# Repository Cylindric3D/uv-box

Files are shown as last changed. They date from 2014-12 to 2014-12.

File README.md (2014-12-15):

Note that documentation and schematics are also available as images in the [GitHub Pages](https://cylindric3d.github.io/uv-box/) site for this project.

Controller Schematic
Controller Board

Important Plots
===============
* Controller Schematic
* Controller Board: B.Cu
* Controller Board: F.SilkS
* LED Panels Schematic
* LED Panels Board: B.Cu

Tips for Creating the PCB
=========================
For creating the PCBs with UV-sensitive boards:

1. Text on the B.Cu layer should appear mirrored
2. Plot only the bottom copper "B.Cu" layer to PDF, do not mirror it - it should look mirrored in the PDF.
   This is because you want the ink to be as close to the photo-sensitive surface of the PCB as possible.
3. Print the B_Cu.pdf onto transparencies suitable for your printer.

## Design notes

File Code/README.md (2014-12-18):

Basic States
------------

* **STATE_STARTUP**
The firmware starts in the Startup state while setting up. In this state no user input is accepted. After startup is complete, the state moves to *STATE_READY*.

* **STATE_READY**
The firmare initially transitions to Ready once it has started up. In this state the user can use the encoder to select a time, and use the button to start the countdown. The LEDs are off. Clicking the button changes the state to *STATE_ACTIVE*.

* **STATE_ACTIVE**
This is the state when the countdown is running, and the LEDs are on. The user can use the button to stop the countdown. Note that the user can still use the encoder to bump the time up or down. After the countdown is complete, the state changes to *STATE_RESETTING*.

* **STATE_RESETTING**
This is a simple reset-state. After a preset time, the display will reset and the state will return to *STATE_READY*.

State Transitions
-----------------
* *STATE_STARTUP*
  * automatically to *STATE_READY*
* *STATE_READY*
  * button-click causes change to *STATE_ACTIVE*
* *STATE_ACTIVE* 
  * button-click causes change to *STATE_RESETTING*
  * countdown complete causes change to *STATE_RESETTING*
* *STATE_RESETTING*
  * automatically to *STATE_READY*

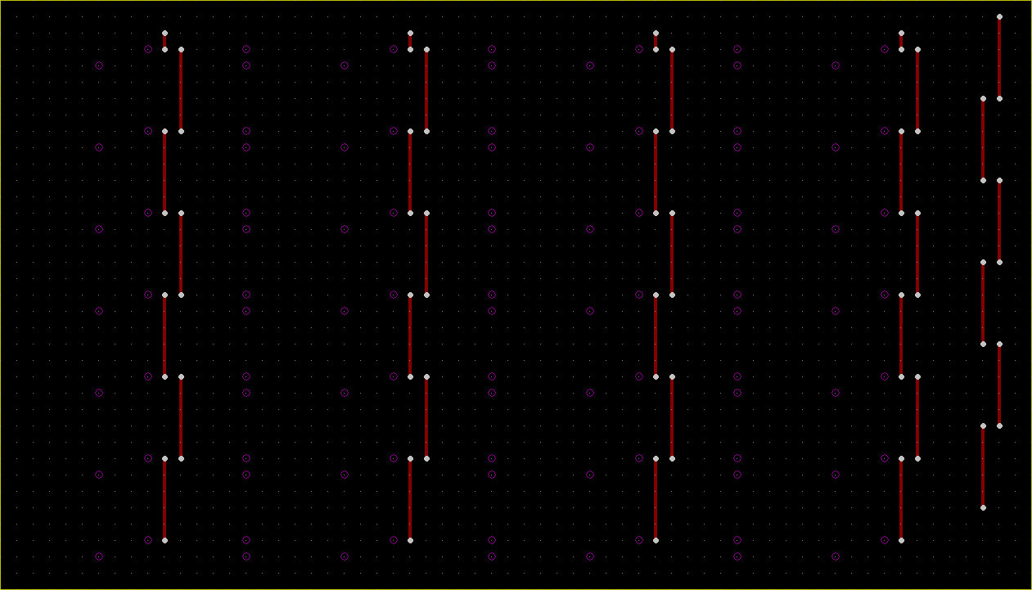
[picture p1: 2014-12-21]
Plans/led_panel-veroboard-bottom.png

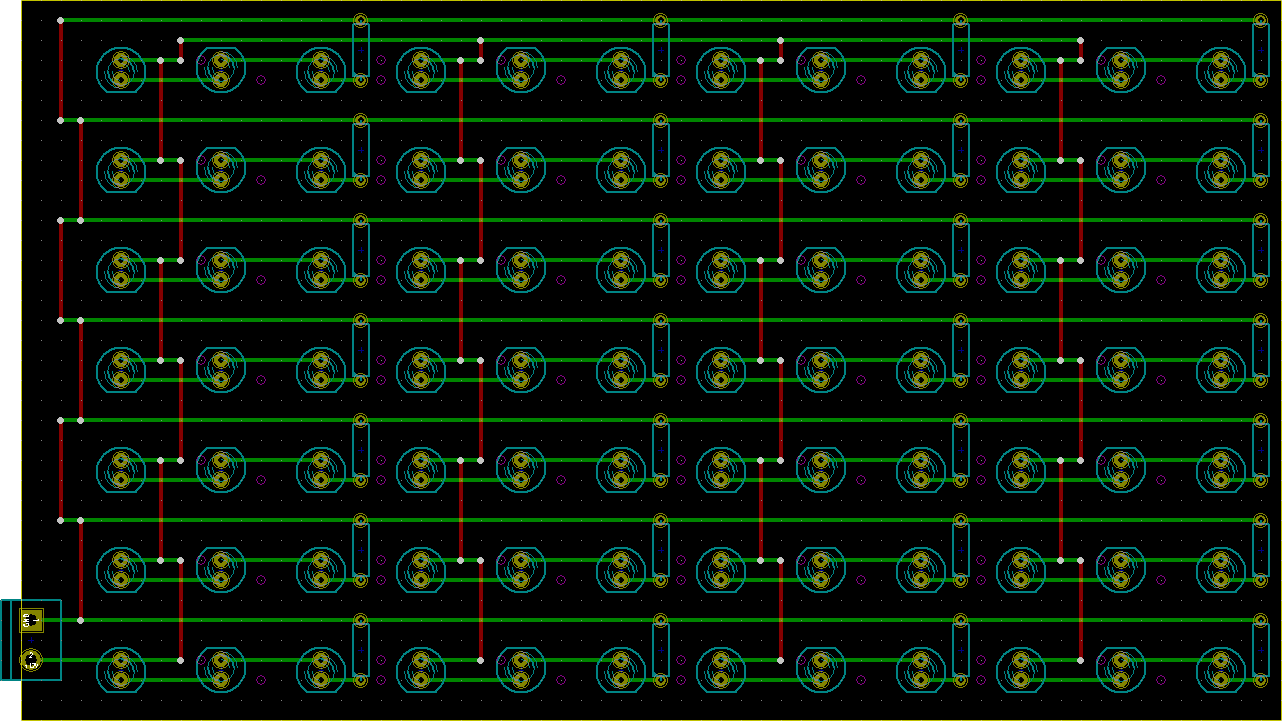
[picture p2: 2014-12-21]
Plans/led_panel-veroboard-top.png

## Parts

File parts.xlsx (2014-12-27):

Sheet: Sheet1
Build
Seller | Part | Item | Ref | Qty | £ Per | £ | PP | Subtotal
 | Controller | Capacitor, ceramic disk: 0.1µF | C4, C1, C2 | 3 |  | £0.00 |  | £0.00
 | Controller | Capacitor, ceramic disk: 0.33µF | C3 | 1 |  | £0.00 |  | £0.00
 | Controller | Resistor: 100kΩ | R4 | 1 |  | £0.00 |  | £0.00
 | Controller | Resistor: 10kΩ | R2 | 1 |  | £0.00 |  | £0.00
 | Controller | Resistor: 120Ω | R12 | 1 |  | £0.00 |  | £0.00
 | Controller | Resistor: 33Ω | R1, R5-11 | 8 |  | £0.00 |  | £0.00
 | Controller | Serial-in, parallel-out shift-register: 74HC595 | U2 | 1 |  | £0.00 |  | £0.00
 | Controller | Rotary Encoder: Alps EC12E2420404 | ENC1 | 1 | £0.77 | £0.77 |  | £0.77
 | Controller | Arduino Pro Micro | U3 | 1 |  | £0.00 |  | £0.00
 | Controller | 4-Digit, 7-segment display: ATA3492BW | LED_DISPLAY1 | 1 | £1.23 | £1.23 |  | £1.23
 | Controller | Voltage regulator, 5V: LM7805 | U1 | 1 |  | £0.00 |  | £0.00
 | Controller | Push-button switch: MULTICOMP TS0B23 | SW1 | 1 | £0.39 | £0.39 |  | £0.39
 | Controller | MOSFET: P55NF | Q1 | 1 |  | £0.00 |  | £0.00
 | Controller | Pin Header Angled | P1, P2, P3 | 6 |  | £0.00 |  | £0.00
 | Controller | DIP Socket | U2 | 16 |  | £0.00 |  | £0.00
 | Controller | SIP Socket | LED_DISPLAY1, U3 | 40 |  | £0.00 |  | £0.00
 | Panel |  |  |  |  | £0.00 |  | £0.00
Seller | Part | Item | Qty | £ Per | £ | PP | Subtotal
eBay | Panel | 50 x Ultra Violet / UV / Purple LED 5mm - 3000mcd - UK Forward Voltage : 3.2v - 3.8v, Forward Current : 20mA | 4 | £3.69 | £14.76 | £0.99 | £15.75
eBay | Panel | 100 x 1/4W 5% Carbon film Resistors - 330Ω | 1 | £0.99 | £0.99 | £0.99 | £1.98 |  | Checked
eBay | Controller | 12V UK DC Power Plug 2A and Power Socket | 1 | £6.99 | £6.99 | £0.00 | £6.99
eBay | Panel | Stripboard PCB Prototyping Vero | 2 | £1.89 | £3.78 | £0.88 | £4.66
CPC | Controller | CLIFF ELECTRONIC COMPONENTS - FC681473 - CONNECTOR, RECEPTACLE, DC POWER, 2.1MM | 1 | £0.38 | £0.38 |  | £0.38
eBay | Box | Strut Hinges For Flight Case Lids - One Pair - Nickel Finish | 1 | £4.49 | £4.49 |  | £4.49
eBay | Box | Clear acrylic 4mmx100mmx200mm | 2 | £3.16 | £6.32 |  | £6.32
eBay | Controller | 1 x Silver Aluminium 6mm Shaft Volume Control Potentiometer Knob Hi-Fi Audio | 1 | £1.99 | £1.99 |  | £1.99
CPC |  | 10-pack HARWIN - M20-9820406 - 0.1" VERTICAL SOCKET 4 WAY | 1 | 4.79 | 4.79 |  | 4.79
CPC | Controller | MULTICOMP - 2226A-08 - CRIMP HOUSING, 1 ROW, 8 WAY | 2 | £0.02 | £0.04 |  | £0.04
CPC | Controller | MULTICOMP - 2226TG - CRIMP TERMINAL, 24-28AWG | 100 | £0.01 | £1.00 |  | £1.00
eBay |  | 10x Ceramic Disc Capacitors 50V 47 values | 1 | £0.99 | £0.99 |  | £0.99
Wickes | Box | WICKES GENERAL PURPOSE MDF BOARD 6X1220X2440MM | 1 | £10.99 | £10.99 |  | £10.99
eBay | Box | Acrylic | 2 | £3.16 | £6.32 |  | £6.32
eBay | Box | M4 Bolts - shorter | 12 |  | £0.00 |  | £0.00
eBay | Box | M4 Bolts - longer | 4 |  | £0.00 |  | £0.00
eBay | Box | M4 Nuts | 16 |  | £0.00 |  | £0.00
 |  | Total |  |  |  |  | £66.69
Consumables
Seller | Part | Item | Qty | £ Per | £ | PP | Subtotal
eBay |  | 50 Sheets Inkjet / Laser Overhead Projector Film OHP A4 LabelHeaven Colour | 1 | £8.95 | £8.95 |  | £8.95
CPC |  | KELAN - 141300 - PCB, PHOTO RESIST, S/S, 100X160MM | 2 | £3.70 | £7.40 |  | £7.40
CPC |  | KELAN - 141301 - PCB, PHOTO RESIST, D/S, 100X160MM | 2 | £3.89 | £7.78 |  | £7.78
CPC |  | KEMO ELECTRONIC - E250 - DEVELOPER, 250G | 1 | £4.04 | £4.04 |  | £4.04
CPC |  | CCL/FCEF/25B - FERRIC CHLORIDE SOLUTION | 1 | £5.62 | £5.62 |  | £5.62
 |  | Total |  |  |  |  | £33.79

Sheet: BOM
REF | Type | Footprint | Value
P1 | Pin Header | 1x12 | PROMICRO_A
P2 | Pin Header | 1x12 | PROMICRO_B
P3 | Connector | Bornier2 | PANEL_2
P4 | Connector | Bornier2 | PANEL_1
P5 | Connector | Bornier3 | DIAL
P6 | Connector | Bornier2 | POWER
Q1 | MOSFET | ? | ?
R1 | Resistor | R3 | 10k
R2 | Resistor | R3 | 10k
R3 | Resistor | R3 | 10k
R4 | Resistor | R3 | 1k
R5 | Resistor | R3 | 330R
U1 | Power | TO-220 | LM317T

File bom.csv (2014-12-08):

source | ref | value | footprint
controller | P3 | PANEL_2 | Connect:bornier2
controller | P2 | PANEL_1 | Connect:bornier2
controller | R9 | 10k | Discret:R3
controller | P4 | DIAL | Connect:bornier3
controller | P1 | POWER | Connect:bornier2
controller | U1 | LM317T | Power_Integrations:TO-220
controller | R10 | 330 | Discret:R3
controller | R11 | 1k | Discret:R3
controller | C2 | 0.1uF | Capacitors_ThroughHole:Capacitor4x3RM2.5
controller | C1 | 0.1uF | Capacitors_ThroughHole:Capacitor4x3RM2.5
controller | P5 | SWITCH | Connect:bornier2
controller | U2 | 74HC595 | Sockets_DIP:DIP-16__300
controller | R2 | 33R | Discret:R3
controller | R6 | 33R | Discret:R3
controller | P6 | LED_DISPLAY | Pin_Headers:Pin_Header_Straight_2x08
controller | R4 | 33R | Discret:R3
controller | R3 | 33R | Discret:R3
controller | R7 | 33R | Discret:R3
controller | R8 | 33R | Discret:R3
controller | R5 | 33R | Discret:R3
controller | R1 | 33R | Discret:R3
controller | U3 | Arduino_Pro_Micro | Cylindric:ArduinoProMicro
controller | Q1 | BUZ11 | Transistors_TO-220:TO-220_FET-GDS_Vertical
led_panels | D19 | LED | LEDs:LED-5MM
led_panels | D20 | LED | LEDs:LED-5MM
led_panels | R7 | 120 | Discret:R3
led_panels | P1 | CONN_2 | Connect:bornier2
led_panels | D21 | LED | LEDs:LED-5MM
led_panels | D13 | LED | LEDs:LED-5MM
led_panels | D14 | LED | LEDs:LED-5MM
led_panels | R5 | 120 | Discret:R3
led_panels | D15 | LED | LEDs:LED-5MM
led_panels | D7 | LED | LEDs:LED-5MM
led_panels | D8 | LED | LEDs:LED-5MM
led_panels | R3 | 120 | Discret:R3
led_panels | D9 | LED | LEDs:LED-5MM
led_panels | D1 | LED | LEDs:LED-5MM
led_panels | D2 | LED | LEDs:LED-5MM
led_panels | R1 | 120 | Discret:R3
led_panels | D3 | LED | LEDs:LED-5MM
led_panels | D37 | LED | LEDs:LED-5MM
led_panels | D38 | LED | LEDs:LED-5MM
led_panels | R13 | 120 | Discret:R3
led_panels | D39 | LED | LEDs:LED-5MM
led_panels | D31 | LED | LEDs:LED-5MM
led_panels | D32 | LED | LEDs:LED-5MM
led_panels | R11 | 120 | Discret:R3
led_panels | D33 | LED | LEDs:LED-5MM
led_panels | D25 | LED | LEDs:LED-5MM
led_panels | D26 | LED | LEDs:LED-5MM
led_panels | R9 | 120 | Discret:R3
led_panels | D27 | LED | LEDs:LED-5MM
led_panels | D61 | LED | LEDs:LED-5MM
led_panels | D62 | LED | LEDs:LED-5MM
led_panels | R21 | 120 | Discret:R3
led_panels | D63 | LED | LEDs:LED-5MM
led_panels | D55 | LED | LEDs:LED-5MM
led_panels | D56 | LED | LEDs:LED-5MM
led_panels | R19 | 120 | Discret:R3
led_panels | D57 | LED | LEDs:LED-5MM
led_panels | D49 | LED | LEDs:LED-5MM
led_panels | D50 | LED | LEDs:LED-5MM
led_panels | R17 | 120 | Discret:R3
led_panels | D51 | LED | LEDs:LED-5MM
led_panels | D43 | LED | LEDs:LED-5MM
led_panels | D44 | LED | LEDs:LED-5MM
led_panels | R15 | 120 | Discret:R3
led_panels | D45 | LED | LEDs:LED-5MM
led_panels | D79 | LED | LEDs:LED-5MM
led_panels | D80 | LED | LEDs:LED-5MM
led_panels | R27 | 120 | Discret:R3
led_panels | D81 | LED | LEDs:LED-5MM
led_panels | D73 | LED | LEDs:LED-5MM
led_panels | D74 | LED | LEDs:LED-5MM
led_panels | R25 | 120 | Discret:R3
led_panels | D75 | LED | LEDs:LED-5MM
led_panels | D67 | LED | LEDs:LED-5MM
led_panels | D68 | LED | LEDs:LED-5MM
led_panels | R23 | 120 | Discret:R3
led_panels | D69 | LED | LEDs:LED-5MM
led_panels | D103 | LED | LEDs:LED-5MM
led_panels | D104 | LED | LEDs:LED-5MM
led_panels | R35 | 120 | Discret:R3
led_panels | D105 | LED | LEDs:LED-5MM
led_panels | D97 | LED | LEDs:LED-5MM
led_panels | D98 | LED | LEDs:LED-5MM
led_panels | R33 | 120 | Discret:R3
led_panels | D99 | LED | LEDs:LED-5MM
led_panels | D91 | LED | LEDs:LED-5MM
led_panels | D92 | LED | LEDs:LED-5MM
led_panels | R31 | 120 | Discret:R3
led_panels | D93 | LED | LEDs:LED-5MM
led_panels | D85 | LED | LEDs:LED-5MM
led_panels | D86 | LED | LEDs:LED-5MM
led_panels | R29 | 120 | Discret:R3
led_panels | D87 | LED | LEDs:LED-5MM
led_panels | D121 | LED | LEDs:LED-5MM
led_panels | D122 | LED | LEDs:LED-5MM
led_panels | R41 | 120 | Discret:R3
led_panels | D123 | LED | LEDs:LED-5MM
led_panels | D115 | LED | LEDs:LED-5MM
led_panels | D116 | LED | LEDs:LED-5MM
led_panels | R39 | 120 | Discret:R3
led_panels | D117 | LED | LEDs:LED-5MM
led_panels | D109 | LED | LEDs:LED-5MM
led_panels | D110 | LED | LEDs:LED-5MM
led_panels | R37 | 120 | Discret:R3
led_panels | D111 | LED | LEDs:LED-5MM
led_panels | D145 | LED | LEDs:LED-5MM
led_panels | D146 | LED | LEDs:LED-5MM
led_panels | R49 | 120 | Discret:R3
led_panels | D147 | LED | LEDs:LED-5MM
led_panels | D139 | LED | LEDs:LED-5MM
led_panels | D140 | LED | LEDs:LED-5MM
led_panels | R47 | 120 | Discret:R3
led_panels | D141 | LED | LEDs:LED-5MM
led_panels | D133 | LED | LEDs:LED-5MM
led_panels | D134 | LED | LEDs:LED-5MM
led_panels | R45 | 120 | Discret:R3
led_panels | D135 | LED | LEDs:LED-5MM
led_panels | D127 | LED | LEDs:LED-5MM
led_panels | D128 | LED | LEDs:LED-5MM
led_panels | R43 | 120 | Discret:R3
led_panels | D129 | LED | LEDs:LED-5MM
led_panels | D163 | LED | LEDs:LED-5MM
led_panels | D164 | LED | LEDs:LED-5MM
led_panels | R55 | 120 | Discret:R3
led_panels | D165 | LED | LEDs:LED-5MM
led_panels | D157 | LED | LEDs:LED-5MM
led_panels | D158 | LED | LEDs:LED-5MM
led_panels | R53 | 120 | Discret:R3
led_panels | D159 | LED | LEDs:LED-5MM
led_panels | D151 | LED | LEDs:LED-5MM
led_panels | D152 | LED | LEDs:LED-5MM
led_panels | R51 | 120 | Discret:R3
led_panels | D153 | LED | LEDs:LED-5MM
led_panels | D22 | LED | LEDs:LED-5MM
led_panels | D23 | LED | LEDs:LED-5MM
led_panels | R8 | 120 | Discret:R3
led_panels | P2 | CONN_2 | Connect:bornier2
led_panels | D24 | LED | LEDs:LED-5MM
led_panels | D16 | LED | LEDs:LED-5MM
led_panels | D17 | LED | LEDs:LED-5MM
led_panels | R6 | 120 | Discret:R3
led_panels | D18 | LED | LEDs:LED-5MM
led_panels | D10 | LED | LEDs:LED-5MM
led_panels | D11 | LED | LEDs:LED-5MM
led_panels | R4 | 120 | Discret:R3
led_panels | D12 | LED | LEDs:LED-5MM
led_panels | D4 | LED | LEDs:LED-5MM
led_panels | D5 | LED | LEDs:LED-5MM
led_panels | R2 | 120 | Discret:R3
led_panels | D6 | LED | LEDs:LED-5MM
led_panels | D40 | LED | LEDs:LED-5MM
led_panels | D41 | LED | LEDs:LED-5MM
led_panels | R14 | 120 | Discret:R3
led_panels | D42 | LED | LEDs:LED-5MM
led_panels | D34 | LED | LEDs:LED-5MM
led_panels | D35 | LED | LEDs:LED-5MM
led_panels | R12 | 120 | Discret:R3
led_panels | D36 | LED | LEDs:LED-5MM
led_panels | D28 | LED | LEDs:LED-5MM
led_panels | D29 | LED | LEDs:LED-5MM
led_panels | R10 | 120 | Discret:R3
led_panels | D30 | LED | LEDs:LED-5MM
led_panels | D64 | LED | LEDs:LED-5MM
led_panels | D65 | LED | LEDs:LED-5MM
led_panels | R22 | 120 | Discret:R3
led_panels | D66 | LED | LEDs:LED-5MM
led_panels | D58 | LED | LEDs:LED-5MM
led_panels | D59 | LED | LEDs:LED-5MM
led_panels | R20 | 120 | Discret:R3
led_panels | D60 | LED | LEDs:LED-5MM
led_panels | D52 | LED | LEDs:LED-5MM
led_panels | D53 | LED | LEDs:LED-5MM
led_panels | R18 | 120 | Discret:R3
led_panels | D54 | LED | LEDs:LED-5MM
led_panels | D46 | LED | LEDs:LED-5MM
led_panels | D47 | LED | LEDs:LED-5MM
led_panels | R16 | 120 | Discret:R3
led_panels | D48 | LED | LEDs:LED-5MM
led_panels | D82 | LED | LEDs:LED-5MM
led_panels | D83 | LED | LEDs:LED-5MM
led_panels | R28 | 120 | Discret:R3
led_panels | D84 | LED | LEDs:LED-5MM
led_panels | D76 | LED | LEDs:LED-5MM
led_panels | D77 | LED | LEDs:LED-5MM
led_panels | R26 | 120 | Discret:R3
led_panels | D78 | LED | LEDs:LED-5MM
led_panels | D70 | LED | LEDs:LED-5MM
led_panels | D71 | LED | LEDs:LED-5MM
led_panels | R24 | 120 | Discret:R3
led_panels | D72 | LED | LEDs:LED-5MM
led_panels | D106 | LED | LEDs:LED-5MM
led_panels | D107 | LED | LEDs:LED-5MM
led_panels | R36 | 120 | Discret:R3
led_panels | D108 | LED | LEDs:LED-5MM
led_panels | D100 | LED | LEDs:LED-5MM
led_panels | D101 | LED | LEDs:LED-5MM
led_panels | R34 | 120 | Discret:R3
led_panels | D102 | LED | LEDs:LED-5MM
led_panels | D94 | LED | LEDs:LED-5MM
led_panels | D95 | LED | LEDs:LED-5MM
led_panels | R32 | 120 | Discret:R3
led_panels | D96 | LED | LEDs:LED-5MM
led_panels | D88 | LED | LEDs:LED-5MM
led_panels | D89 | LED | LEDs:LED-5MM
led_panels | R30 | 120 | Discret:R3
led_panels | D90 | LED | LEDs:LED-5MM
led_panels | D124 | LED | LEDs:LED-5MM
led_panels | D125 | LED | LEDs:LED-5MM
led_panels | R42 | 120 | Discret:R3
led_panels | D126 | LED | LEDs:LED-5MM
led_panels | D118 | LED | LEDs:LED-5MM
led_panels | D119 | LED | LEDs:LED-5MM
led_panels | R40 | 120 | Discret:R3
led_panels | D120 | LED | LEDs:LED-5MM
led_panels | D112 | LED | LEDs:LED-5MM
led_panels | D113 | LED | LEDs:LED-5MM
led_panels | R38 | 120 | Discret:R3
led_panels | D114 | LED | LEDs:LED-5MM
led_panels | D148 | LED | LEDs:LED-5MM
led_panels | D149 | LED | LEDs:LED-5MM
led_panels | R50 | 120 | Discret:R3
led_panels | D150 | LED | LEDs:LED-5MM
led_panels | D142 | LED | LEDs:LED-5MM
led_panels | D143 | LED | LEDs:LED-5MM
led_panels | R48 | 120 | Discret:R3
led_panels | D144 | LED | LEDs:LED-5MM
led_panels | D136 | LED | LEDs:LED-5MM
led_panels | D137 | LED | LEDs:LED-5MM
led_panels | R46 | 120 | Discret:R3
led_panels | D138 | LED | LEDs:LED-5MM
led_panels | D130 | LED | LEDs:LED-5MM
led_panels | D131 | LED | LEDs:LED-5MM
led_panels | R44 | 120 | Discret:R3
led_panels | D132 | LED | LEDs:LED-5MM
led_panels | D166 | LED | LEDs:LED-5MM
led_panels | D167 | LED | LEDs:LED-5MM
led_panels | R56 | 120 | Discret:R3
led_panels | D168 | LED | LEDs:LED-5MM
led_panels | D160 | LED | LEDs:LED-5MM
led_panels | D161 | LED | LEDs:LED-5MM
led_panels | R54 | 120 | Discret:R3
led_panels | D162 | LED | LEDs:LED-5MM
led_panels | D154 | LED | LEDs:LED-5MM
led_panels | D155 | LED | LEDs:LED-5MM
led_panels | R52 | 120 | Discret:R3
led_panels | D156 | LED | LEDs:LED-5MM
digit_board | P1 | LED_DISPLAY | Pin_Headers:Pin_Header_Straight_2x08
digit_board | LED_DISPLAY1 | ATA3492BW | Cylindric:4DIG_7SEG_ATA3492BW

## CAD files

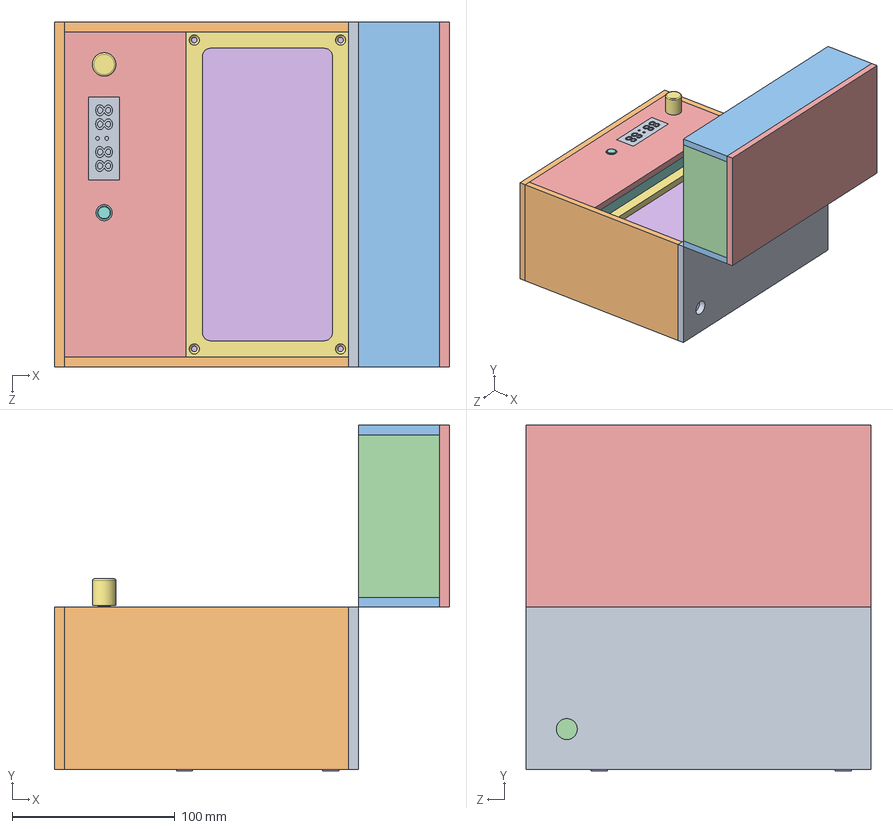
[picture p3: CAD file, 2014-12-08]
Box/Box.SLDASM
243.0 x 212.7 x 212.0 mm
bottom-base
bottom-side x 2
bottom-left-side x 2
bottom-frontinsert
bottom-controlpanel
bottom-backinsert
bottom-windowledge
bottom-step
bottom-back
bottom-front
top-front x 2
top-side x 2
top-top
bottom-window
knob
Push Switch
4-Digit 7-Segment
top-windowledge
top-posts x 4
top-window
PCB
bottom-posts x 4
controller

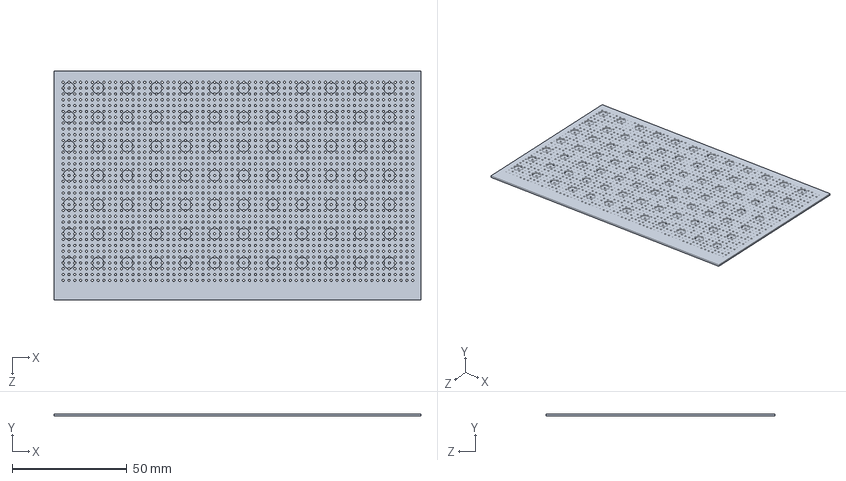
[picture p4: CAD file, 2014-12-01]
Electronics/PCB.SLDPRT
160.0 x 1.00 x 100.0 mm

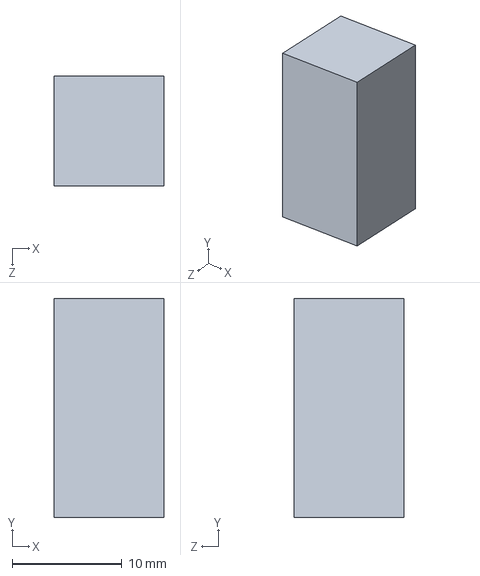
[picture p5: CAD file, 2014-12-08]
Box/top-posts.SLDPRT
10.0 x 20.0 x 10.0 mm

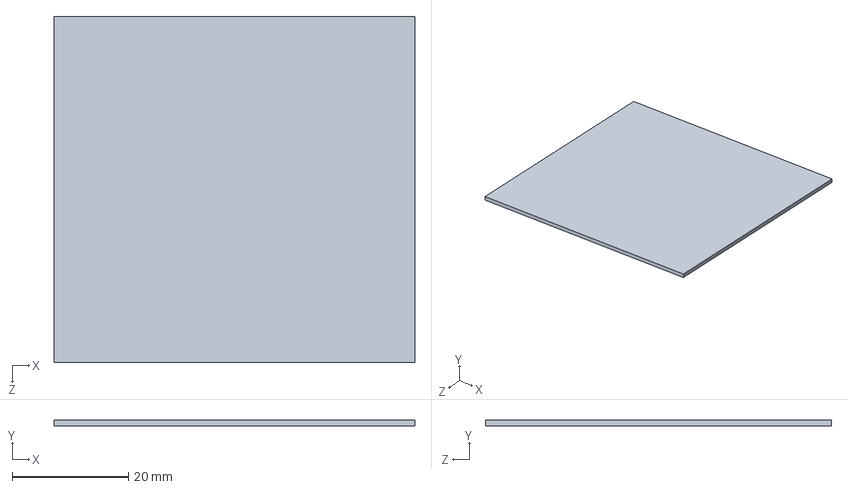
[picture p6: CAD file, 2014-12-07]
Box/controller.SLDPRT
62.2 x 1.00 x 59.7 mm

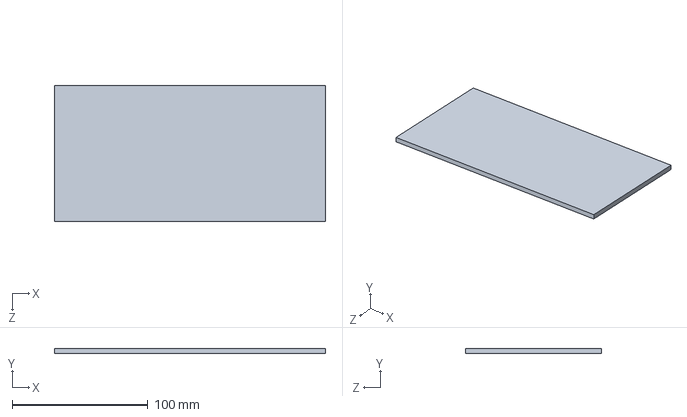
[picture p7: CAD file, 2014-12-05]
Box/top-window.SLDPRT
200.0 x 4.00 x 100.0 mm

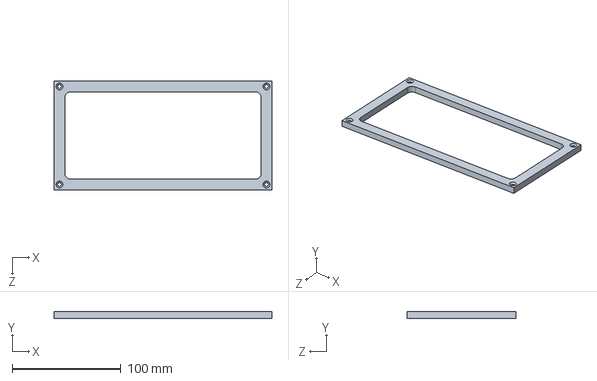
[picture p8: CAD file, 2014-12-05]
Box/bottom-windowledge.SLDPRT
200.0 x 6.00 x 100.0 mm

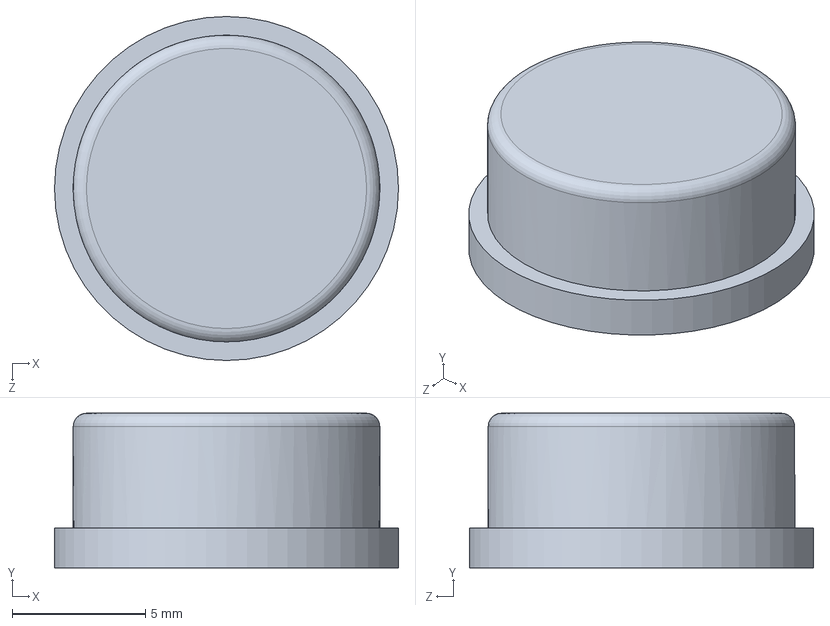
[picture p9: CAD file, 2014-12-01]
Box/tactilebutton.SLDPRT
12.9 x 5.80 x 12.9 mm

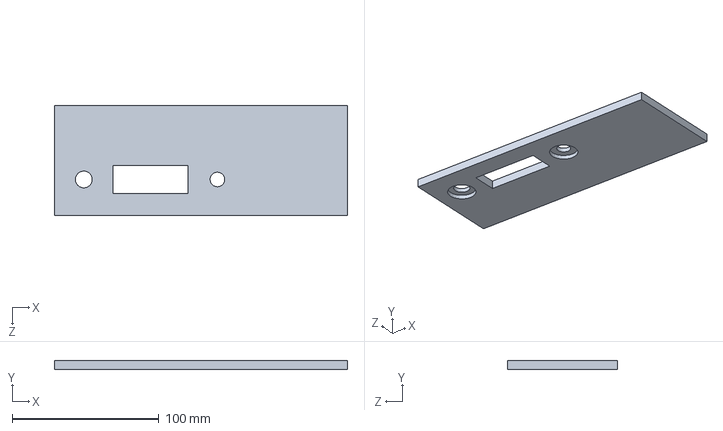
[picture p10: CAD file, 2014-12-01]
Box/bottom-controlpanel.SLDPRT
200.0 x 6.00 x 75.0 mm

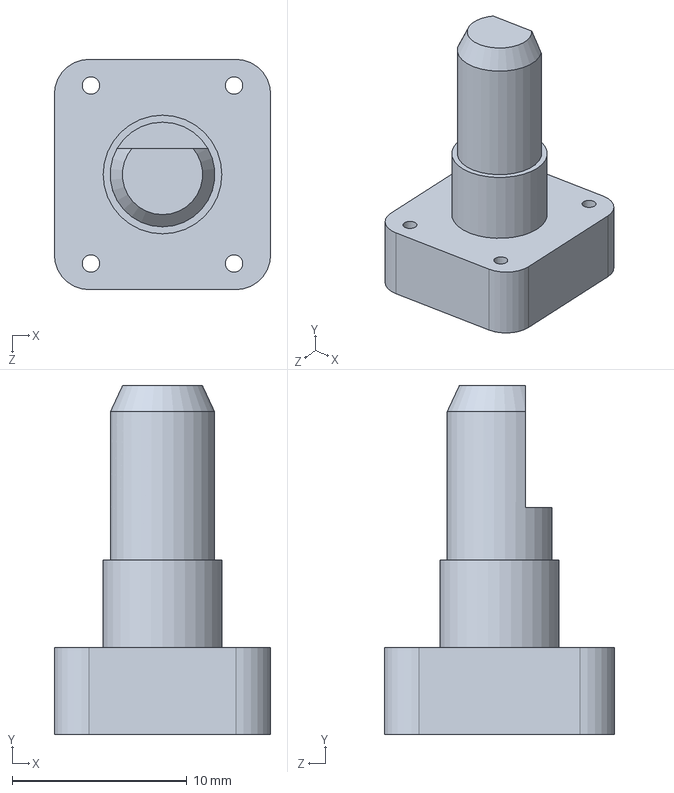
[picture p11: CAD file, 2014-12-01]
Box/Rotary Encoder.SLDPRT
12.4 x 20.0 x 13.2 mm

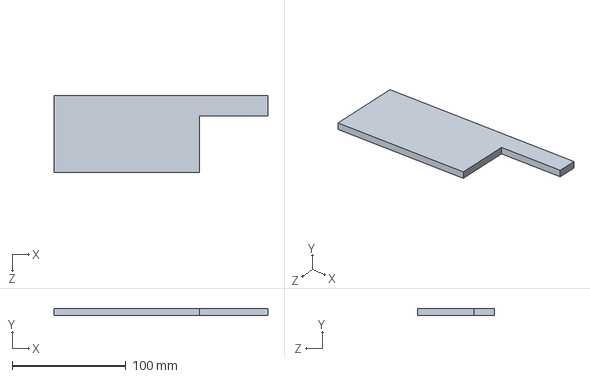
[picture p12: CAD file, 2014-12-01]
Box/bottom-backinsert.SLDPRT
188.0 x 6.00 x 68.0 mm

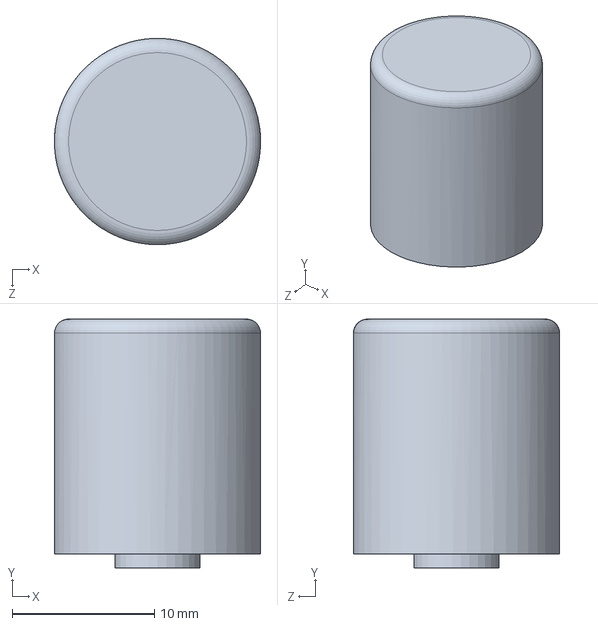
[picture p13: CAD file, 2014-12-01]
Box/knob.SLDPRT
14.5 x 17.5 x 14.5 mm

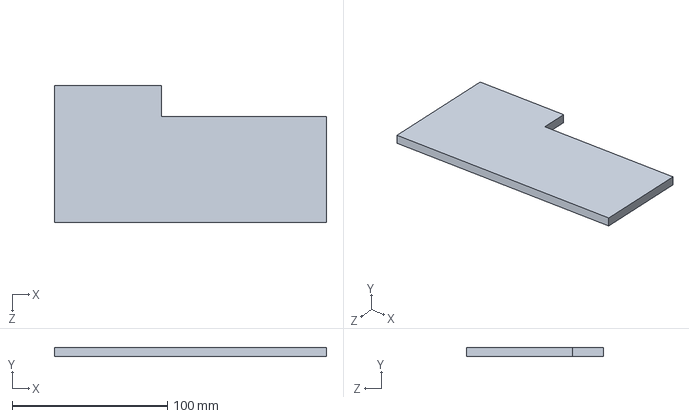
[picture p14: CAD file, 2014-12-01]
Box/bottom-left-side.SLDPRT
175.0 x 6.00 x 88.0 mm

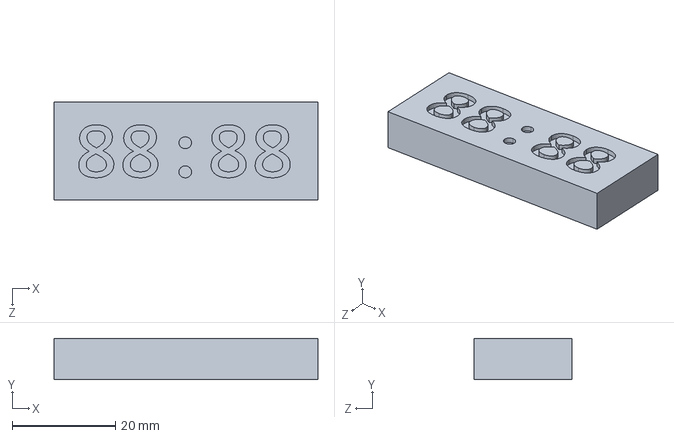
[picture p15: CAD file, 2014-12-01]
Box/4-Digit 7-Segment.SLDPRT
51.2 x 8.00 x 19.1 mm

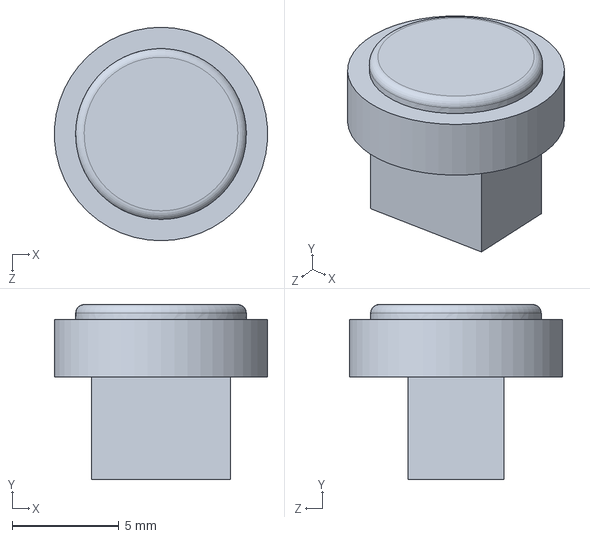
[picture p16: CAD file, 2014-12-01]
Box/Push Switch.SLDPRT
9.98 x 8.20 x 10.0 mm

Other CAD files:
Box/bottom-posts.SLDPRT
Box/top-windowledge.SLDPRT
Box/bottom-back.SLDPRT
Box/bottom-base.SLDPRT
Box/bottom-front.SLDPRT
Box/bottom-frontback.SLDPRT
Box/bottom-frontinsert.SLDPRT
Box/bottom-side.SLDPRT
Box/bottom-sideinsert.SLDPRT
Box/bottom-step.SLDPRT
Box/plans.SLDDRW
Box/top-back.SLDPRT
Box/top-front.SLDPRT
Box/top-side.SLDPRT
Box/top-top.SLDPRT
Box/top_posts.SLDPRT

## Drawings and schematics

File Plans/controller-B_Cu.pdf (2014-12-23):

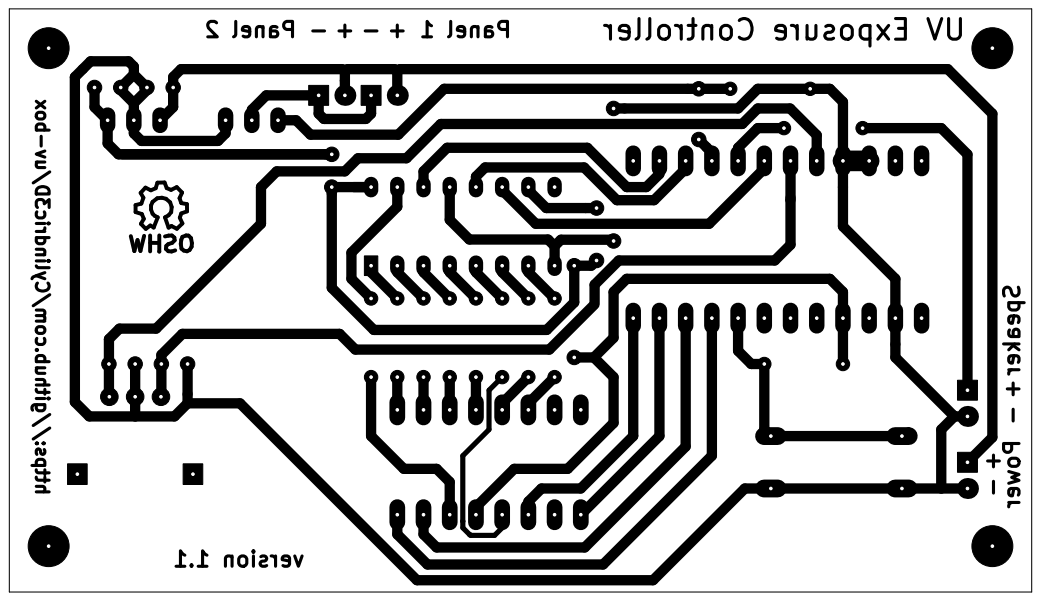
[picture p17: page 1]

+ https://github.com/Cylindric3D/uv-box Panel 2 - + - + Panel 1 - - + Speaker Power version 1.1 UV Exposure Controller

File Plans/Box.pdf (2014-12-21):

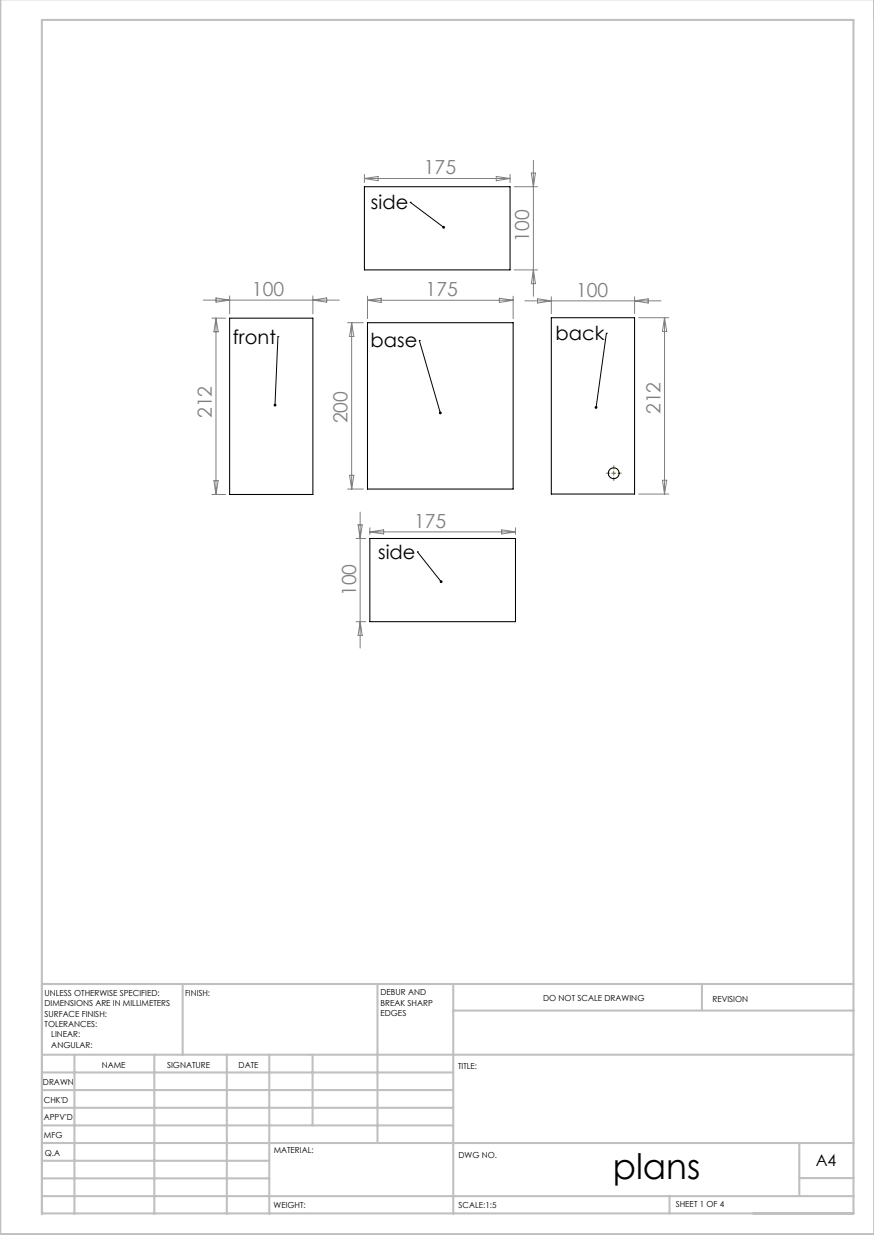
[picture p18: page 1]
SCALE:1:5; SHEET 1 OF 4; DO NOT SCALE DRAWING; REVISION; DEBUR AND BREAK SHARP; UNLESS OTHERWISE SPECIFIED:; FINISH:

DIMENSIONS ARE IN MILLIMETERS
SURFACE FINISH:
TOLERANCES:
LINEAR:
ANGULAR:

NAME | SIGNATURE | DATE | | | | TITLE:

DRAWN
CHK'D
APPV'D
MFG
Q.A | | | | MATERIAL: | plans WEIGHT: DWG NO. | A4

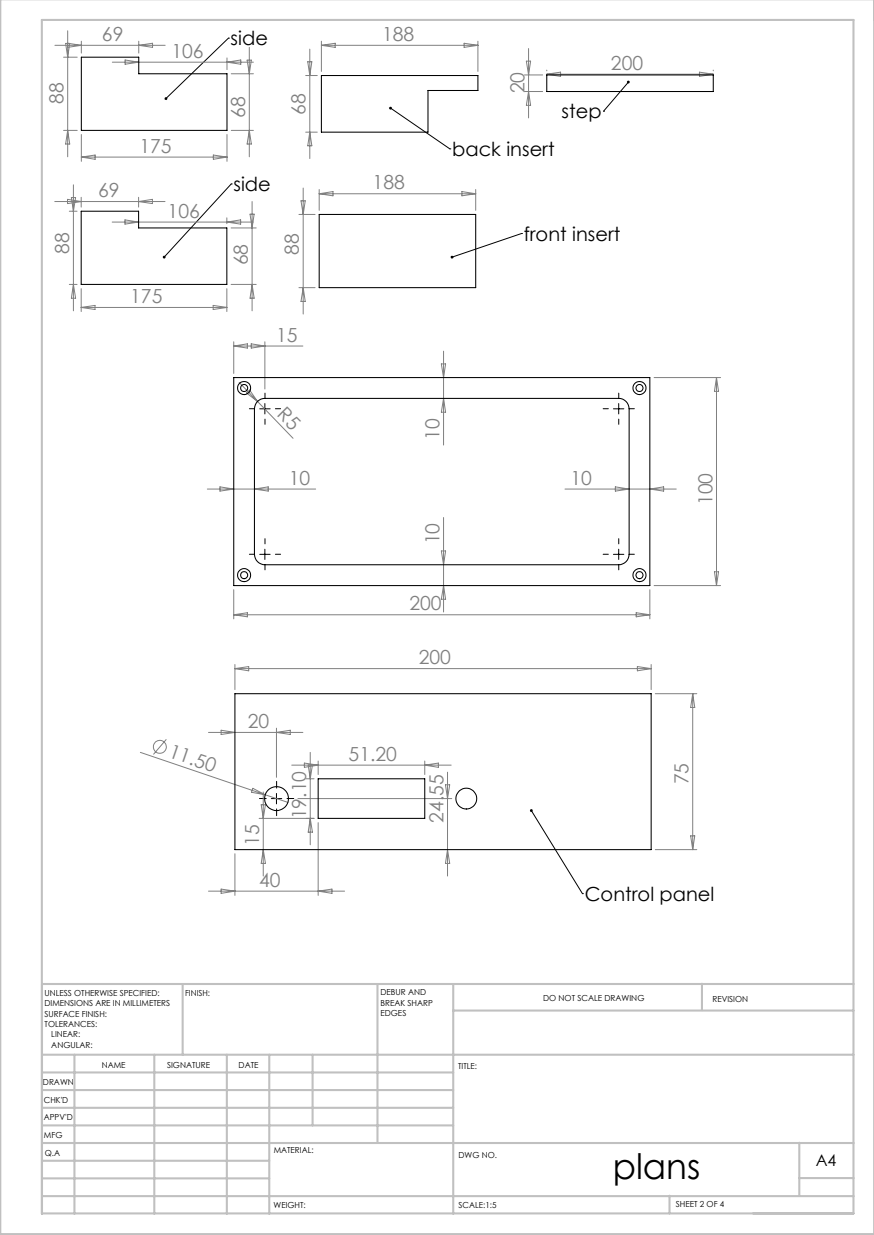
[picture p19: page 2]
back insert; front insert; Control panel; DO NOT SCALE DRAWING; REVISION; DEBUR AND BREAK SHARP; UNLESS OTHERWISE SPECIFIED:; FINISH:

DIMENSIONS ARE IN MILLIMETERS
SURFACE FINISH:
TOLERANCES:
LINEAR:
ANGULAR:

NAME | SIGNATURE | DATE | TITLE:

DRAWN
CHK'D
APPV'D

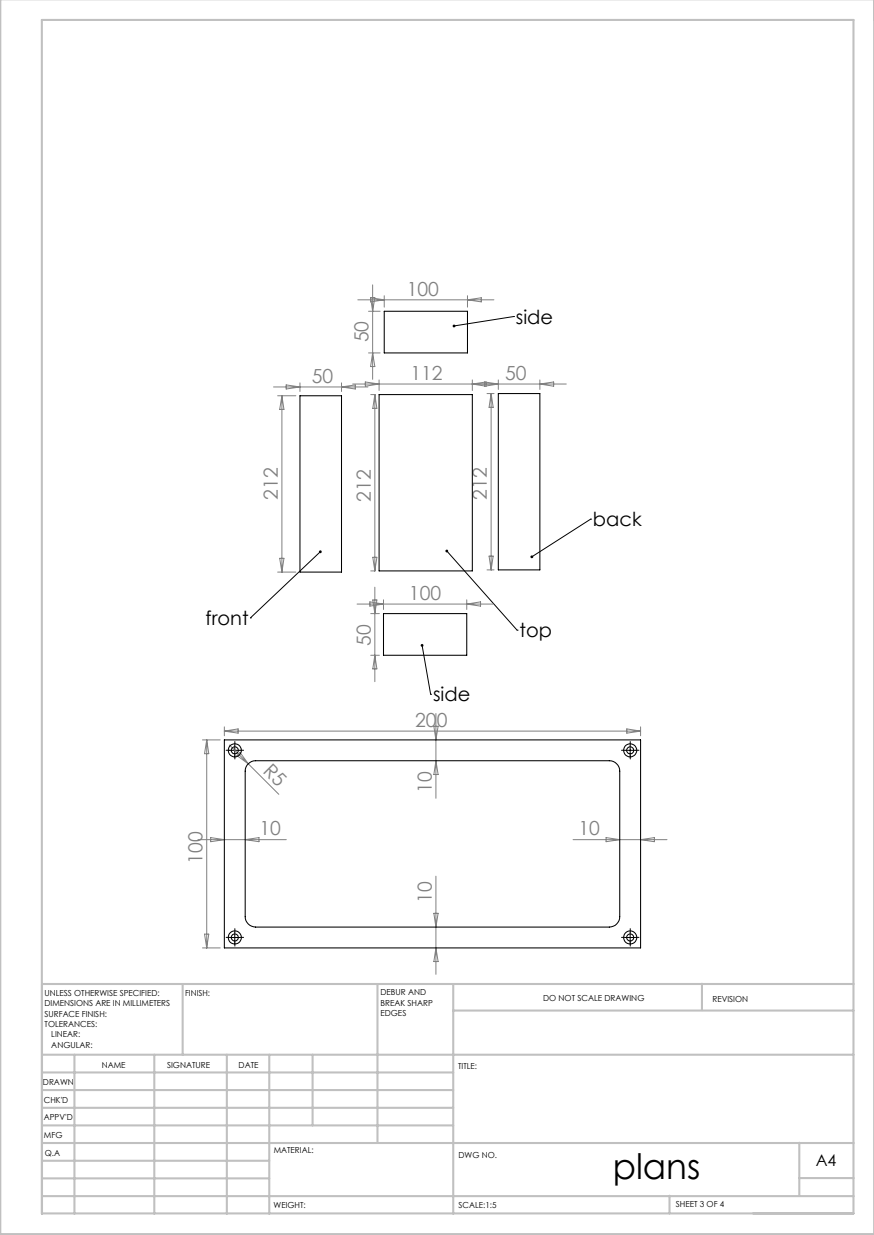
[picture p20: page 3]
DO NOT SCALE DRAWING; REVISION; DEBUR AND BREAK SHARP; UNLESS OTHERWISE SPECIFIED:; FINISH:

DIMENSIONS ARE IN MILLIMETERS
SURFACE FINISH:
TOLERANCES:
LINEAR:
ANGULAR:

NAME | SIGNATURE | DATE | TITLE:

DRAWN
CHK'D
APPV'D

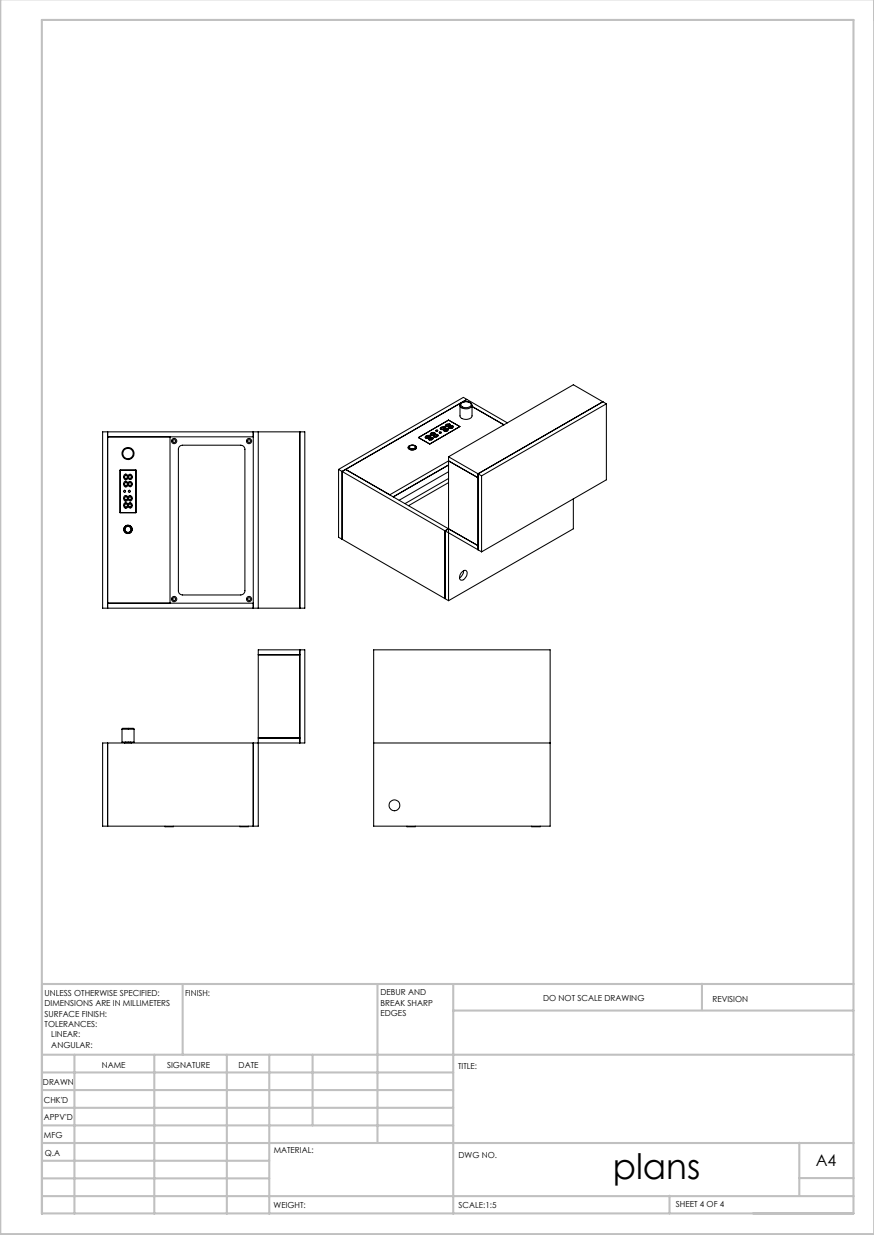
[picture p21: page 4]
DO NOT SCALE DRAWING; REVISION; DEBUR AND BREAK SHARP; UNLESS OTHERWISE SPECIFIED:; FINISH:

DIMENSIONS ARE IN MILLIMETERS
SURFACE FINISH:
TOLERANCES:
LINEAR:
ANGULAR:

NAME | SIGNATURE | DATE | TITLE:

DRAWN
CHK'D
APPV'D

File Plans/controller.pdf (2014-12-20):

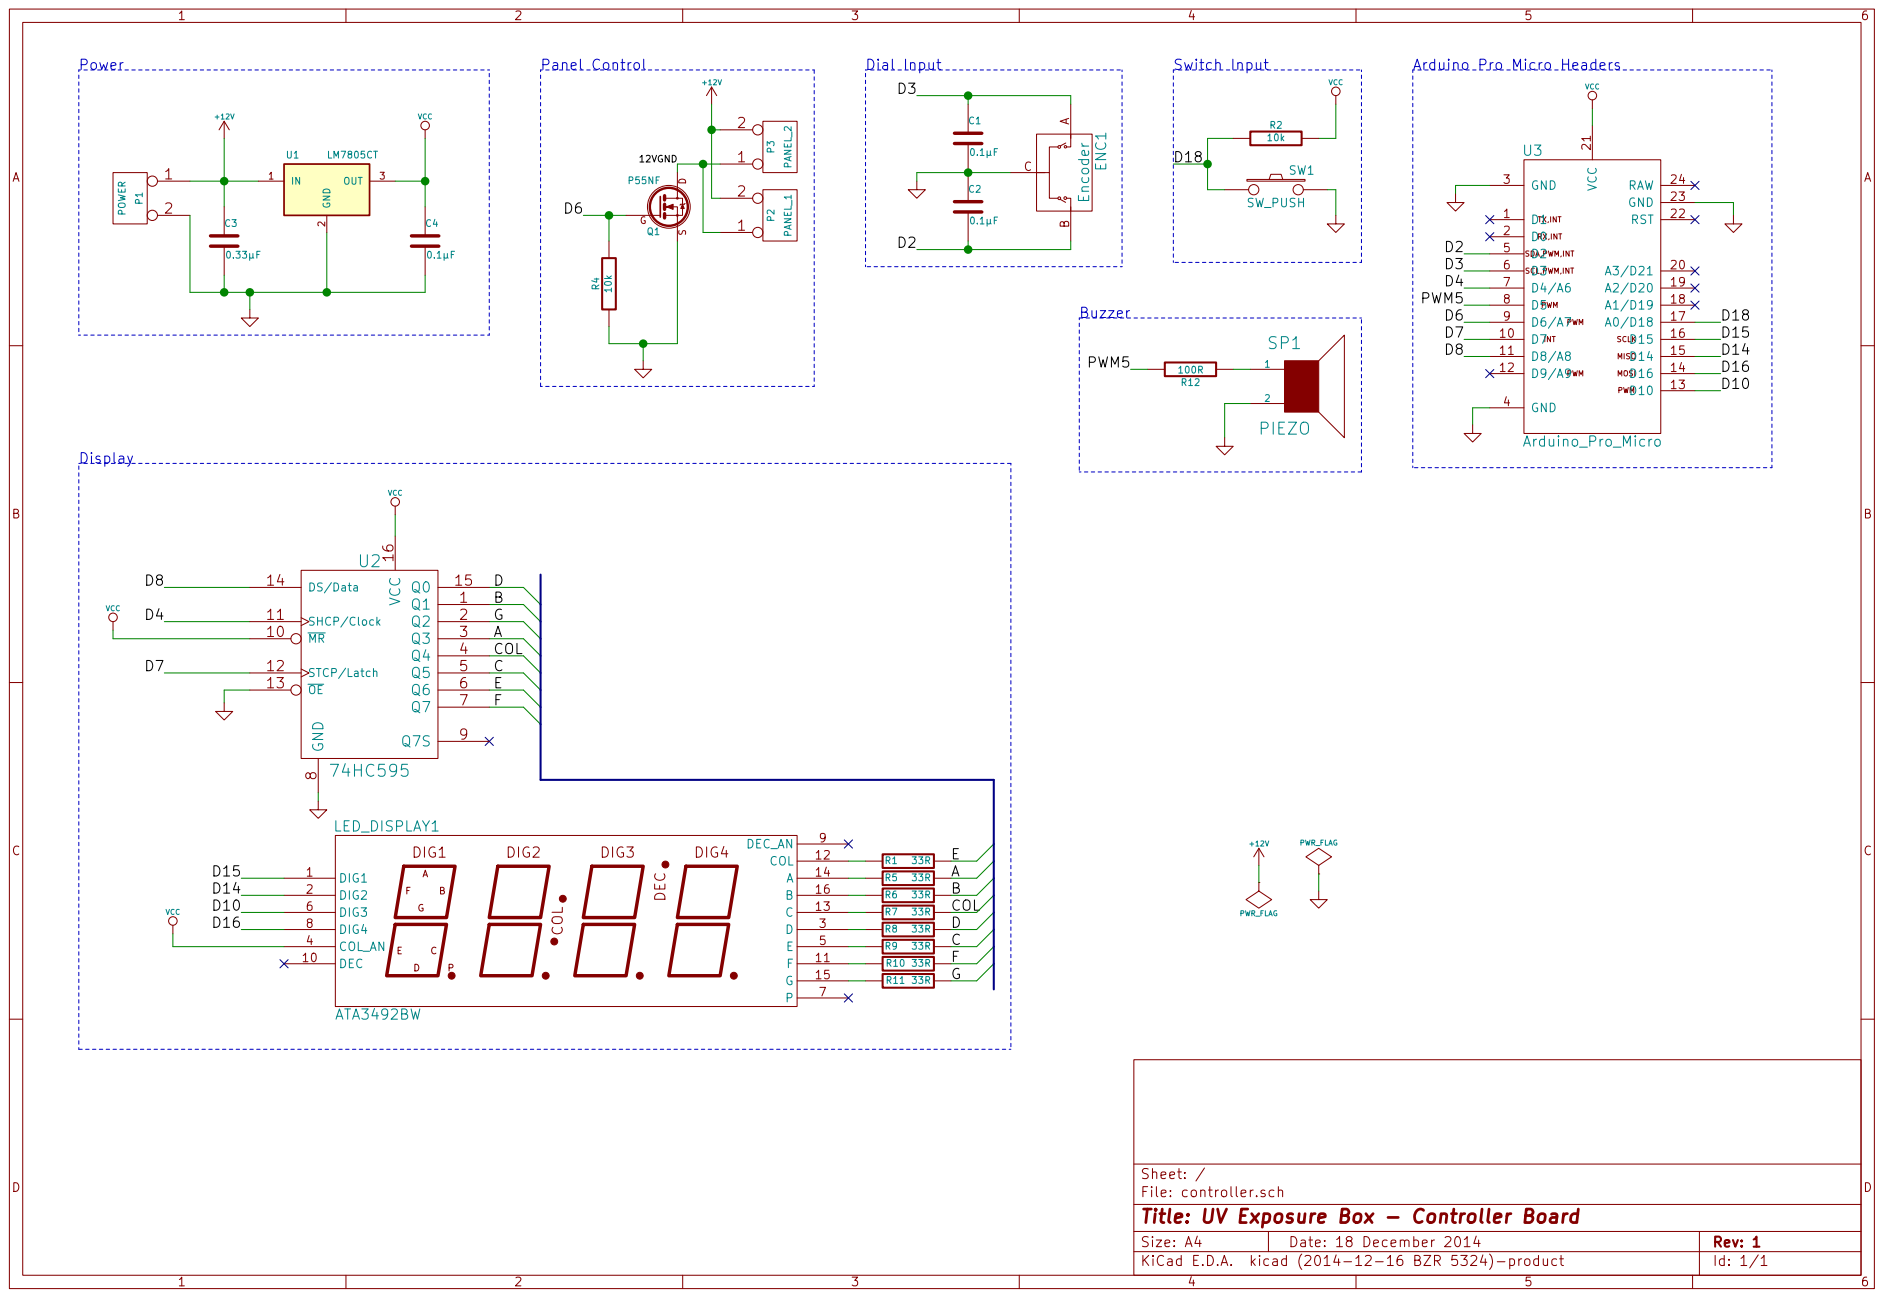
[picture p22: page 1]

14 G | BC
15 B | D

File: controller.sch Sheet: /
Id: 1/1 Title: UV Exposure Box - Controller Board

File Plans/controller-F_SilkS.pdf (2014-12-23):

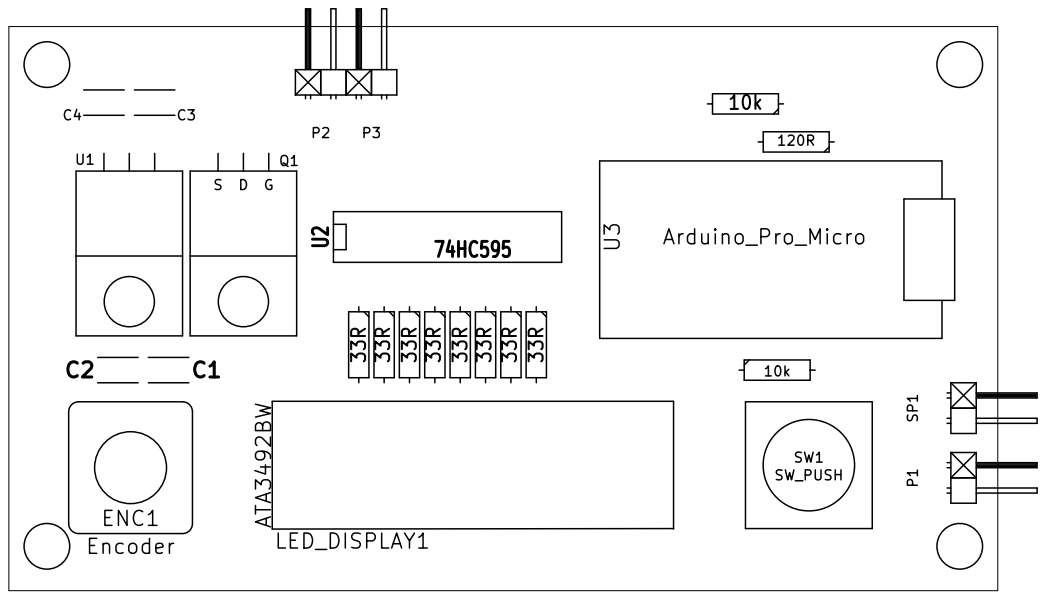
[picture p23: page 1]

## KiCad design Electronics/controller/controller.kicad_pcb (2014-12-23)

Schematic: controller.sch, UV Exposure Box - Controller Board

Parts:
C1, C2, C4: 0.1µF; Capacitor4x3RM2.5
C3: 0.33µF; Capacitor4x3RM2.5
ENC1: Encoder; ALPS_Encoder-EC12E2420404
LED_DISPLAY1: ATA3492BW; 4_Digit-7_Segment_LED-ATA3492BW
P1: POWER; Pin_Header_Angled_1x02
P2: PANEL_1; Pin_Header_Angled_1x02
P3: PANEL_2; Pin_Header_Angled_1x02
Q1: P55NF; TO-220_FET-GDS_Horizontal
R1, R5, R6, R7, R8, R9, R10, R11: 33R; R3
R2, R4: 10k; R3
R12: 120R; R3
SP1: PIEZO; Pin_Header_Angled_1x02
SW1: SW_PUSH; SW_PUSH-12mm
U1: LM7805CT; TO-220_Neutral123_Horizontal
U2: 74HC595; DIP-16__300
U3: Arduino_Pro_Micro; ArduinoProMicro

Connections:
+12V: C3.1, P1.1, P2.2 (PM), P3.2 (PM), U1.1
/12VGND: P2.1, P3.1, Q1.D
/A: R5.1, U2.3
/B: R6.1, U2.1
/C: R7.1, U2.4
/COL: R1.1, U2.6
/D: R8.1, U2.15
/D2: C2.2, ENC1.B, U3.5
/D3: C1.1, ENC1.A, U3.6
/D4: U2.11, U3.7
/D6: Q1.G, R4.2, U3.9
/D7: U2.12, U3.10
/D8: U2.14, U3.11
/D10: LED_DISPLAY1.6, U3.13
/D14: LED_DISPLAY1.2, U3.15
/D15: LED_DISPLAY1.1, U3.16
/D16: LED_DISPLAY1.8, U3.14
/D18: R2.1, SW1.1, U3.17
/E: R9.1, U2.5
/F: R10.1, U2.7
/G: R11.1, U2.2
/PWM5: R12.2, U3.8
GND: C1.2, C2.1, C3.2, C4.2, ENC1.C, P1.2 (PM), Q1.S, R4.1, SP1.2, SW1.2, U1.2, U2.8, U2.13, U3.3, U3.4, U3.23
unnamed: LED_DISPLAY1.3, R8.2
unnamed: LED_DISPLAY1.5, R9.2
unnamed: LED_DISPLAY1.11, R10.2
unnamed: LED_DISPLAY1.12, R1.2
unnamed: LED_DISPLAY1.13, R7.2
unnamed: LED_DISPLAY1.14, R5.2
unnamed: LED_DISPLAY1.15, R11.2
unnamed: LED_DISPLAY1.16, R6.2
unnamed: R12.1, SP1.1
VCC: C4.1, LED_DISPLAY1.4, R2.2, U1.3, U2.10, U2.16, U3.21

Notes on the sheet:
Power
Panel Control
Dial Input
Arduino Pro Micro Headers
Switch Input
Display
Buzzer

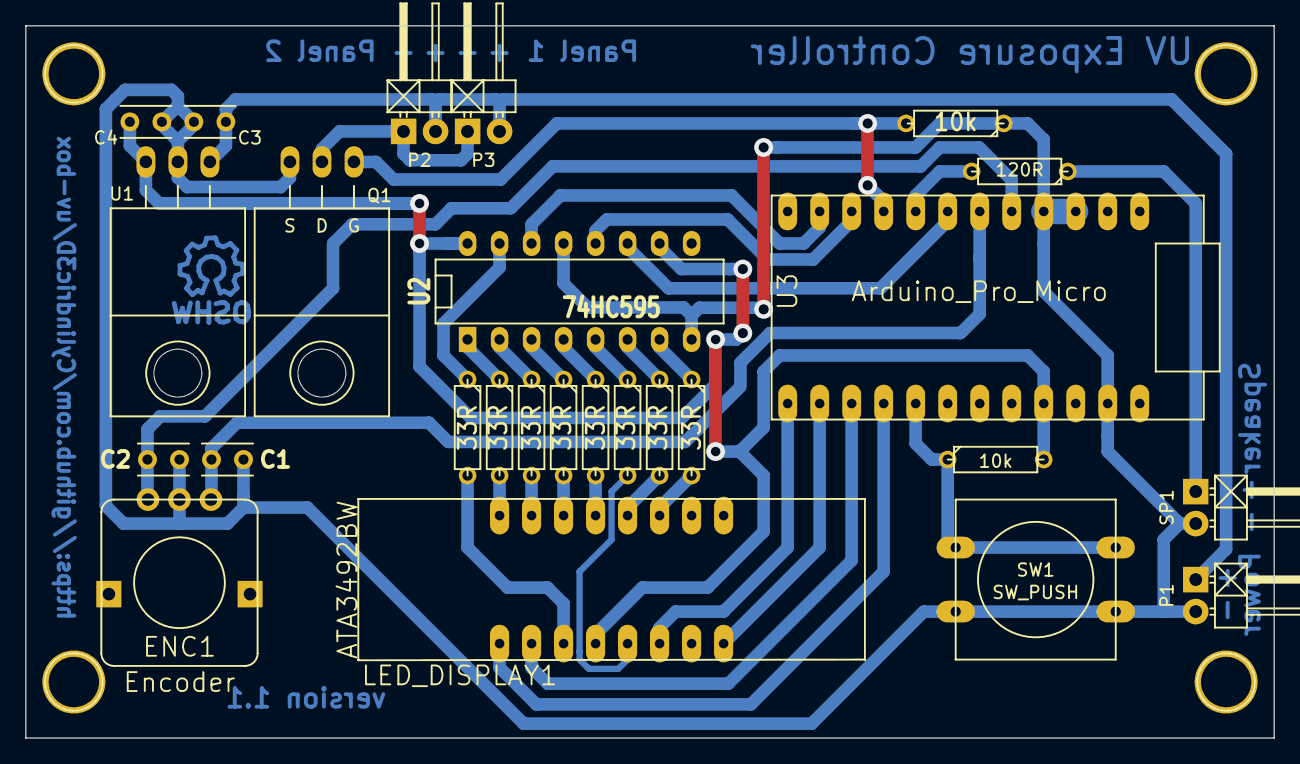
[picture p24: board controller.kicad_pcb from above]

Board: 2 copper layers, 99.1 x 56.5 mm, 31 parts (1 on the bottom side), 33 nets.

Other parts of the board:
1pin, 1pin#2, 1pin#3, 1pin#4: VAL**; 1pin
Symbol_OSHW-Logo_CopperTop: VAL**; Symbol_OSHW-Logo_CopperTop

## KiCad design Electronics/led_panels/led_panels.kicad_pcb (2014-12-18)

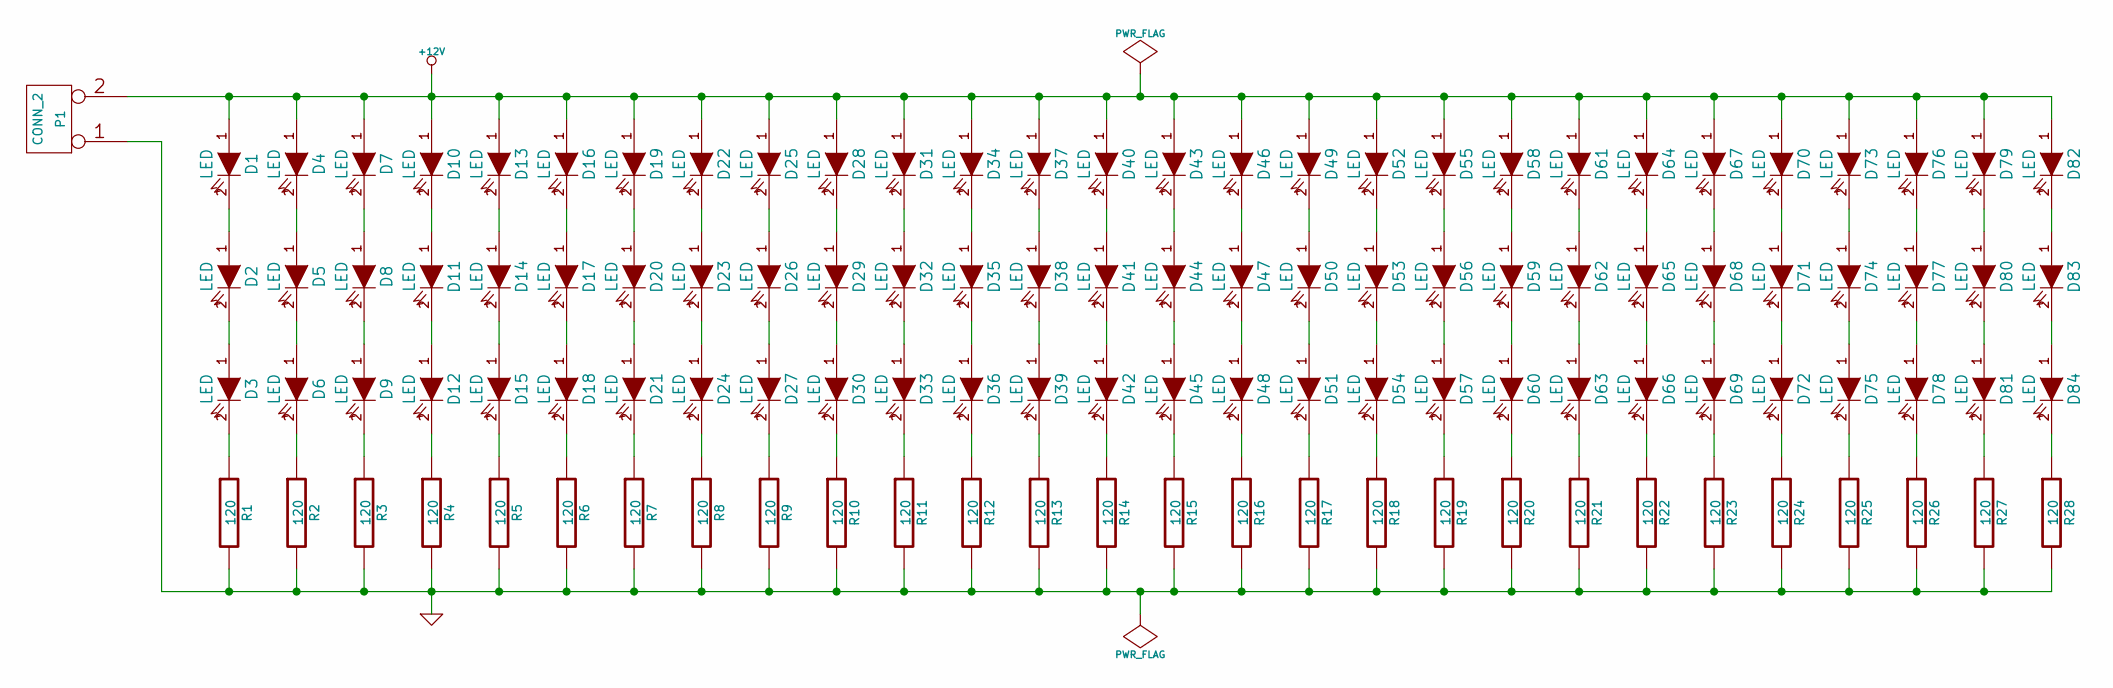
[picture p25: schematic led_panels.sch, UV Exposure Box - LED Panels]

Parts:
D1, D2, D3, D4, D5, D6, D7, D8, D9, D10, D11, D12, D13, D14, D15, D16, D17, D18, D19, D20, D21, D22, D23, D24, D25, D26, D27, D28, D29, D30, D31, D32, D33, D34, D35, D36, D37, D38, D39, D40, D41, D42, D43, D44, D45, D46, D47, D48, D49, D50, D51, D52, D53, D54, D55, D56, D57, D58, D59, D60, D61, D62, D63, D64, D65, D66, D67, D68, D69, D70, D71, D72, D73, D74, D75, D76, D77, D78, D79, D80, D81, D82, D83, D84: LED; LED-5MM
P1: CONN_2; bornier2
R1, R2, R3, R4, R5, R6, R7, R8, R9, R10, R11, R12, R13, R14, R15, R16, R17, R18, R19, R20, R21, R22, R23, R24, R25, R26, R27, R28: 120; R3

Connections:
+12V: D1.1 (A), D4.1 (A), D7.1 (A), D10.1 (A), D13.1 (A), D16.1 (A), D19.1 (A), D22.1 (A), D25.1 (A), D28.1 (A), D31.1 (A), D34.1 (A), D37.1 (A), D40.1 (A), D43.1 (A), D46.1 (A), D49.1 (A), D52.1 (A), D55.1 (A), D58.1 (A), D61.1 (A), D64.1 (A), D67.1 (A), D70.1 (A), D73.1 (A), D76.1 (A), D79.1 (A), D82.1 (A), P1.2 (PM)
GND: P1.1, R1.2, R2.2, R3.2, R4.2, R5.2, R6.2, R7.2, R8.2, R9.2, R10.2, R11.2, R12.2, R13.2, R14.2, R15.2, R16.2, R17.2, R18.2, R19.2, R20.2, R21.2, R22.2, R23.2, R24.2, R25.2, R26.2, R27.2, R28.2
unnamed: D1.2 (K), D2.1 (A)
unnamed: D2.2 (K), D3.1 (A)
unnamed: D3.2 (K), R1.1
unnamed: D4.2 (K), D5.1 (A)
unnamed: D5.2 (K), D6.1 (A)
unnamed: D6.2 (K), R2.1
unnamed: D7.2 (K), D8.1 (A)
unnamed: D8.2 (K), D9.1 (A)
unnamed: D9.2 (K), R3.1
unnamed: D10.2 (K), D11.1 (A)
unnamed: D11.2 (K), D12.1 (A)
unnamed: D12.2 (K), R4.1
unnamed: D13.2 (K), D14.1 (A)
unnamed: D14.2 (K), D15.1 (A)
unnamed: D15.2 (K), R5.1
unnamed: D16.2 (K), D17.1 (A)
unnamed: D17.2 (K), D18.1 (A)
unnamed: D18.2 (K), R6.1
unnamed: D19.2 (K), D20.1 (A)
unnamed: D20.2 (K), D21.1 (A)
unnamed: D21.2 (K), R7.1
unnamed: D22.2 (K), D23.1 (A)
unnamed: D23.2 (K), D24.1 (A)
unnamed: D24.2 (K), R8.1
unnamed: D25.2 (K), D26.1 (A)
unnamed: D26.2 (K), D27.1 (A)
unnamed: D27.2 (K), R9.1
unnamed: D28.2 (K), D29.1 (A)
unnamed: D29.2 (K), D30.1 (A)
unnamed: D30.2 (K), R10.1
unnamed: D31.2 (K), D32.1 (A)
unnamed: D32.2 (K), D33.1 (A)
unnamed: D33.2 (K), R11.1
unnamed: D34.2 (K), D35.1 (A)
unnamed: D35.2 (K), D36.1 (A)
unnamed: D36.2 (K), R12.1
unnamed: D37.2 (K), D38.1 (A)
unnamed: D38.2 (K), D39.1 (A)
unnamed: D39.2 (K), R13.1
unnamed: D40.2 (K), D41.1 (A)
unnamed: D41.2 (K), D42.1 (A)
unnamed: D42.2 (K), R14.1
unnamed: D43.2 (K), D44.1 (A)
unnamed: D44.2 (K), D45.1 (A)
unnamed: D45.2 (K), R15.1
unnamed: D46.2 (K), D47.1 (A)
unnamed: D47.2 (K), D48.1 (A)
unnamed: D48.2 (K), R16.1
unnamed: D49.2 (K), D50.1 (A)
unnamed: D50.2 (K), D51.1 (A)
unnamed: D51.2 (K), R17.1
unnamed: D52.2 (K), D53.1 (A)
unnamed: D53.2 (K), D54.1 (A)
unnamed: D54.2 (K), R18.1
unnamed: D55.2 (K), D56.1 (A)
unnamed: D56.2 (K), D57.1 (A)
unnamed: D57.2 (K), R19.1
unnamed: D58.2 (K), D59.1 (A)
unnamed: D59.2 (K), D60.1 (A)
unnamed: D60.2 (K), R20.1
unnamed: D61.2 (K), D62.1 (A)
unnamed: D62.2 (K), D63.1 (A)
unnamed: D63.2 (K), R21.1
unnamed: D64.2 (K), D65.1 (A)
unnamed: D65.2 (K), D66.1 (A)
unnamed: D66.2 (K), R22.1
unnamed: D67.2 (K), D68.1 (A)
unnamed: D68.2 (K), D69.1 (A)
unnamed: D69.2 (K), R23.1
unnamed: D70.2 (K), D71.1 (A)
unnamed: D71.2 (K), D72.1 (A)
unnamed: D72.2 (K), R24.1
unnamed: D73.2 (K), D74.1 (A)
unnamed: D74.2 (K), D75.1 (A)
unnamed: D75.2 (K), R25.1
unnamed: D76.2 (K), D77.1 (A)
unnamed: D77.2 (K), D78.1 (A)
unnamed: D78.2 (K), R26.1
unnamed: D79.2 (K), D80.1 (A)
unnamed: D80.2 (K), D81.1 (A)
unnamed: D81.2 (K), R27.1
unnamed: D82.2 (K), D83.1 (A)
unnamed: D83.2 (K), D84.1 (A)
unnamed: D84.2 (K), R28.1

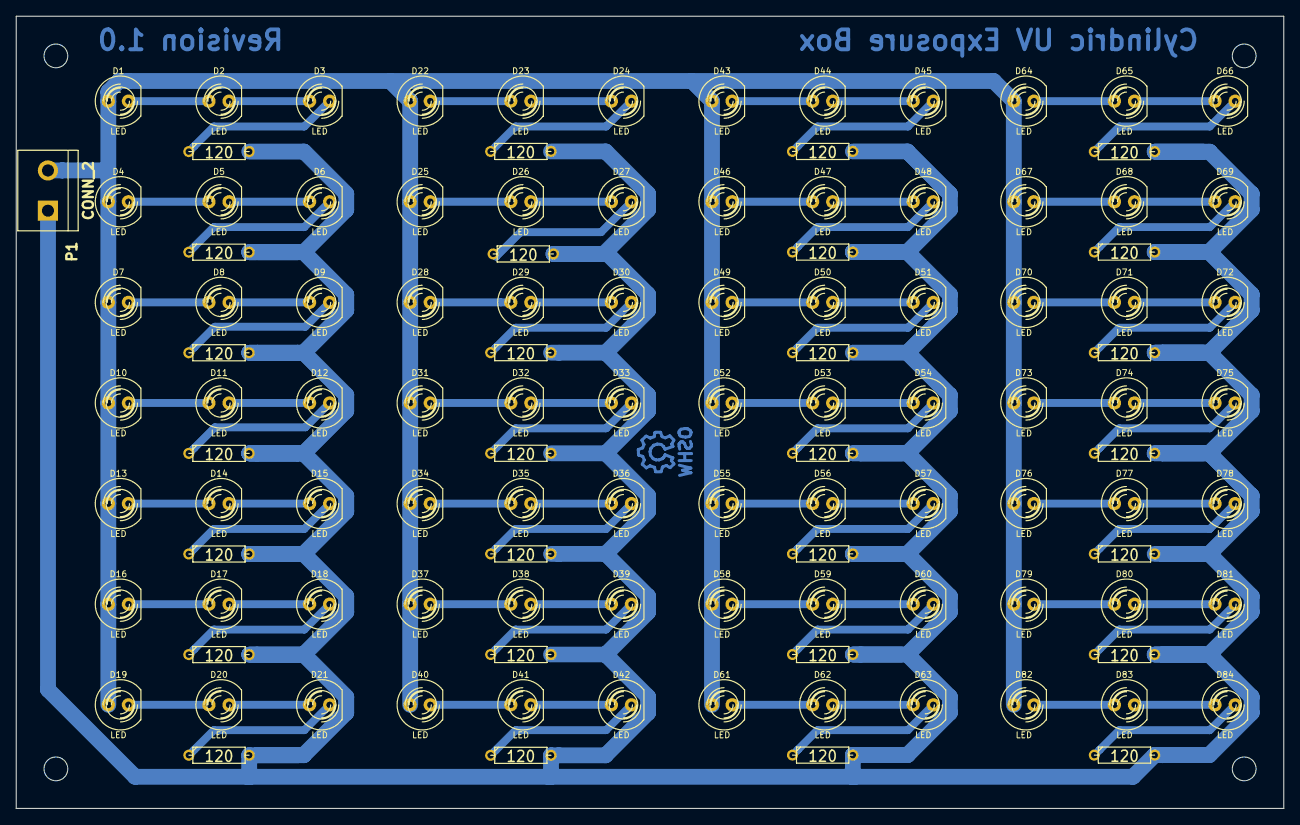
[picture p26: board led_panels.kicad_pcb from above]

Board: 2 copper layers, 160.0 x 100.0 mm, 118 parts (1 on the bottom side), 86 nets.

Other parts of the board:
MountingHole_3mm, MountingHole_3mm#2, MountingHole_3mm#3, MountingHole_3mm#4: VAL**; MountingHole_3mm
Symbol_OSHW-Logo_CopperTop: VAL**; Symbol_OSHW-Logo_CopperTop

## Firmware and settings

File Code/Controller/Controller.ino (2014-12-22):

#include <EEPROM.h>
#include "Encoder.h"

#include "beep.h"
#include "button.h"
#include "clock.h"
#include "memory.h"
#include "panel.h"

/* ***********************************************/
/* DEFINE THE PHYISICAL PINS USED ON THE ARDUINO */
/* ***********************************************/

// SHIFT_X_PIN are the three inputs to the shift-register.
const int SHIFT_LATCH_PIN = 7;
const int SHIFT_CLOCK_PIN = 4;
const int SHIFT_DATA_PIN = 8;

// DIGIT_X_PIN are the four digit-enable pins.
const int DIGIT_1_PIN = 15;
const int DIGIT_2_PIN = 14;
const int DIGIT_3_PIN = 10;
const int DIGIT_4_PIN = 16;

// ENCODER_PIN_x are the two inputs from the encoder.
const int ENCODER_PIN_A = 2;
const int ENCODER_PIN_B = 3;

// PANEL_ENABLE_PIN is the trigger for the main LED control.
const int PANEL_ENABLE_PIN = 6;

// START_BUTTON_PIN is the main 'go' button.
const int START_BUTTON_PIN = 18;

// BEEP_PIN is the buzzer pin.
const int BEEP_PIN = 5;

/* ***********************************************/
/* SETUP THE PARAMETERS                          */
/* ***********************************************/

// Each physical 'click' of the encoder results in this many increments of the encoder counter.
const int ENCODER_STEPS_PER_CLICK = 4;

// The number of seconds to beep for.
const int TOTAL_COUNTDOWN_BEEPS = 3;

// How long to wait before resetting the clock display.
const int CLOCK_RESET_DELAY = 2000;


/* ***********************************************/
/* START                                         */
/* ***********************************************/

Beep beep(BEEP_PIN);
Button button(START_BUTTON_PIN);
Clock clock;
Encoder encoder(ENCODER_PIN_A, ENCODER_PIN_B);
Memory memory;
Panel panel(PANEL_ENABLE_PIN);



const int STATE_STARTUP    = 1; // Controller is still starting up.
const int STATE_READY      = 2; // Ready for input from the user.
const int STATE_ACTIVE     = 4; // Countdown is running and lamps are on.
const int STATE_RESETTING  = 8; // Countdown is complete and clock will reset.



// state is used to track the current state of the controller.
int state;

unsigned long last_state_change = 0;



void setState(int newstate)
{
	state = newstate;
	last_state_change = millis();
	Serial.print("New state is "); Serial.println(newstate);
}



void setup()
{
	state = STATE_STARTUP;
	Serial.begin(9600);
	delay(1000);

	button.setInvert(true);
	
	clock.setShifterPins(SHIFT_LATCH_PIN, SHIFT_CLOCK_PIN, SHIFT_DATA_PIN);
	clock.setDigitPins(DIGIT_1_PIN, DIGIT_2_PIN, DIGIT_3_PIN, DIGIT_4_PIN);
	clock.stopBlinkingColon(true);
	clock.setSeconds(memory.getClockSeconds());
	
	encoder.write(memory.getClockSeconds() * ENCODER_STEPS_PER_CLICK);
	
	Serial.println("Started LED Exposure Controller.");
	beep.melodyUp();
	
	setState(STATE_READY);
}

bool alarm_activated = false;
int encoderValue = -999;


void loop() 
{
	// Refresh the button.
	button.update();
	
	// Refresh the clock.
	clock.update();
	
	// Refresh the beeper.
	beep.update();
	
	// Refresh the encoder.
	int newEncoderValue = encoder.read();
	
	
	// Process encoder input
	if(newEncoderValue != encoderValue)
	{
		// Clamp to zero
		if(newEncoderValue < 0)
		{
			newEncoderValue = 0;
			encoder.write(0);
		}
		
		// ignore small movements
		if(abs(newEncoderValue - encoderValue) > 3)
		{
			encoderValue = newEncoderValue;
			memory.setClockSeconds(encoderValue / ENCODER_STEPS_PER_CLICK);
			clock.setSeconds(memory.getClockSeconds());
			Serial.print("Encoder: "); Serial.println(encoderValue);
		}
		
	}
	

	// See if the button has been clicked
	static bool last_button_state = false;
	bool button_state = button.read();
	if(button_state == true && last_button_state == false) // falling edge
	{
		Serial.println("Button pressed!");
		
		// The button press has been detected
		if(STATE_ACTIVE & state)
		{
			// The button was pressed while the countdown is running
			// Stop the countdown
			Serial.println("Stopping countdown.");
			clock.stopBlinkingColon(true);
			clock.stopCountdown();
			setState(STATE_RESETTING);
			panel.off();
		}
		else if(STATE_READY & state)
		{
			// The button was pressed while the countdown is not running
			// Start the countdown
			Serial.print("Starting countdown at "); Serial.println(millis());
			clock.startBlinkingColon();
			clock.startCountdown();
			setState(STATE_ACTIVE);
			panel.on();
		}
		else
		{
			Serial.println("Doing nothing");
		}

	}
	last_button_state = button_state;

	
	// If we're resetting the clock display for any reason, do it now
	if(STATE_RESETTING & state)
	{
		if(last_state_change + CLOCK_RESET_DELAY <= millis())
		{
			clock.setSeconds(memory.getClockSeconds());
			setState(STATE_READY);
		}
	}


	// If the countdown is running and we're near the end, start beeping.
	static int countdownbeeps = TOTAL_COUNTDOWN_BEEPS;
	if(state == STATE_ACTIVE && countdownbeeps == clock.getSeconds() + 1)
	{
		beep.beep(Beep::b, 200);
		countdownbeeps--;
	}

	
	
	// The countdown has finished
	if(clock.getAlarm())
	{
		Serial.print("Alarm triggered at "); Serial.println(millis());
		clock.clearAlarm();
		clock.stopBlinkingColon(true);
		panel.off();
		setState(STATE_RESETTING);
		beep.beep(Beep::fH, 600);
		countdownbeeps = TOTAL_COUNTDOWN_BEEPS;
		memory.save();
	}

}

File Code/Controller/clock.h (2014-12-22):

#ifndef Clock_h
#define Clock_h

#include "Arduino.h"

// Bit values for defining connections between the shift-register and the LED segments
const int SHIFT_PIN_1  =   1;
const int SHIFT_PIN_2  =   2;
const int SHIFT_PIN_3  =   4;
const int SHIFT_PIN_4  =   8;
const int SHIFT_PIN_5  =  16;
const int SHIFT_PIN_6  =  32;
const int SHIFT_PIN_7  =  64;
const int SHIFT_PIN_15 = 128;

const byte BIT_A   = SHIFT_PIN_4;
const byte BIT_B   = SHIFT_PIN_2;
const byte BIT_C   = SHIFT_PIN_5;
const byte BIT_D   = SHIFT_PIN_1;
const byte BIT_E   = SHIFT_PIN_6;
const byte BIT_F   = SHIFT_PIN_15;
const byte BIT_G   = SHIFT_PIN_3;
const byte BIT_COL = SHIFT_PIN_7;

class Clock
{
	public:
		// Constructor
		Clock();
		
		// Set the pins connected to the shift register.
		void setShifterPins(int latch, int clock, int data);
		
		// Set the pins connected to the four digit-enable pins.
		void setDigitPins(int digit_1, int digit_2, int digit_3, int digit_4);
		
		// Call update to recalculate the state of the clock and to cause an update.
		void update();
		
		// Set the current time on the clock, in seconds. 
		// Values lower than zero will be clamped to zero.
		// Resets the state of getAlarm().
		void setSeconds(int seconds);
		
		// Start counting down the clock. A time must first be set with setSecods().
		void startCountdown();
		
		// Stop counting down the clock.
		void stopCountdown();
		
		// Start blinking the colon.
		void startBlinkingColon();
		
		// Stop blinking the colon, leaving it in the final_state.
		void stopBlinkingColon(bool final_state = false);
		
		// Get the current time on the clock, in seconds.
		int getSeconds();
		
		// Get the current state of the alarm. Returns true if a countdown has expired; else false.
		bool getAlarm();
		
		// Clear a current alarm state.
		void clearAlarm();
		
		
	private:
		// Storage register clock is pin 12 on the 74HC595, and might be labelled ST_CP
		int _latch_pin;

		// Shift register clock is pin 11 on the 74HC595, and might be labelled SH_CP
		int _clock_pin;

		// Serial data input is pin 14 on the 74HC595, and might be labelled DS or SER
		int _data_pin;

		// _digit_pins are the four pins connected to the four anodes of the display, left to right
		int _digit_pins[4];

		//seven segment digits in bits
		byte _digit[10];
		
		int _display_mode;
		int _digit_buffer[4];
		int _digit_scan;
		bool _colon_blinking;
		bool _colon_enabled;
		bool _countdown_running;
		bool _countdown_alarm;
		unsigned long _clock_time_ms;
		unsigned long _clock_started_ms;
		unsigned long _countdown_ms;
		unsigned long _colon_lastchanged_ms;
		int _last_second;

		void display();

};

#endif

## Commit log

2014-11-29 Initial tests.
    [parts.xlsx, uv-box.kicad_pcb, uv-box.sch]
2014-11-30 84 LED per panel.
    [uv-box.kicad_pcb, uv-box.sch]
2014-12-01 Full model of the box. Some updated parts for the parts list.
    [Box.SLDASM, PCB.SLDPRT, bottom window.SLDPRT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]
2014-12-01 Add second panel, and controller.
    [uv-box.sch]
2014-12-01 Update box blueprints.
    [4-Digit 7-Segment.SLDPRT, Box.SLDASM, Push Switch.SLDPRT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]
2014-12-02 Update schematics.
    [controller.kicad_pcb, controller.sch, led_panels.kicad_pcb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]
2014-12-02 Update parts.
    [parts.xlsx]
2014-12-02 Updated board layout. Tidied up schematic.
    [controller.kicad_pcb, controller.sch, led_panels.sch]
2014-12-02 Add display driver schematic.
    [Box.SLDASM, controller.kicad_pcb, controller.sch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]
2014-12-03 Added a script to extract a BOM from the netlists.
2014-12-03 Couple of minor fixes.
    [led_panels.sch]
2014-12-04 Totally broken display.
    [controller.sch]
2014-12-05 Update plans.
    [Box.SLDASM, bottom window.SLDPRT, bottom-posts.SLDPRT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]
2014-12-05 Update schematics with new single-SIPO implementation.
    [bom.csv, controller.kicad_pcb, controller.sch]
2014-12-06 Fix layout.
    [controller.kicad_pcb, controller.sch]
2014-12-07 Created a small breakout board for the LED display.
    [digit_board.kicad_pcb, digit_board.sch]
2014-12-07 Renumbered some sockets. Rerouted pins.
    [controller.kicad_pcb, controller.sch]
2014-12-07 Teaks to the plans - added a sample of the PCB.
    [Box.SLDASM, controller.SLDPRT]
2014-12-08 Renamed my library.
    [controller.sch]
2014-12-09 Trying out a PCB-based LED panel instead of Veroboard.
    [led_panels-pcb.kicad_pcb, led_panels.sch, parts.xlsx]
2014-12-10 Almost ready for production.
    [controller.kicad_pcb, controller.sch, led_panels-pcb.kicad_pcb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]
2014-12-10 Tweaking some layout stuff.
    [controller.sch, led_panels.kicad_pcb]
2014-12-10 Putting the display onto the board directly.
    [controller.kicad_pcb, controller.sch]
2014-12-11 Reworking controller board.
    [controller.kicad_pcb, controller.sch]
2014-12-11 Update with single layout board.
    [controller.kicad_pcb, controller.sch]
2014-12-11 Added missing file.
    [controller.sch]
2014-12-12 Added the OSHW logo to the controller.
    [controller.kicad_pcb, controller.sch, led_panels.sch]
2014-12-13 Playing with layout.
    [controller.kicad_pcb]
2014-12-15 Change a couple of footprints.
    [controller.kicad_pcb, controller.sch]
2014-12-15 Updated code with current pins from the schematic. Refactored display code.
2014-12-15 Trying out the hardware.
    [controller.kicad_pcb]
2014-12-16 Fixed some bad pinouts on the 7-seg.
    [controller.kicad_pcb, controller.sch]
2014-12-17 Updated schematics after prototype testing.
    [controller.kicad_pcb, controller.sch]
2014-12-18 Moved some parts around on the board.
    [controller.kicad_pcb, controller.sch, led_panels.kicad_pcb]
2014-12-18 Tidied up some visual layout issues.
    [controller.kicad_pcb, controller.sch, led_panels.sch]
2014-12-18 Added the LED to the custom library to be able to hide pin numbers.
2014-12-18 Got rid of old pcb layout.
    [led_panels.kicad_pcb]
2014-12-20 Brought back the old veroboard layout - turns out it's better than protoboard :)
    [led_panels-veroboard.kicad_pcb]
2014-12-20 Added some plots for the v1 controller board.
    [controller.kicad_pcb]
2014-12-20 Made board more home-brew friendly.
    [controller.kicad_pcb, controller.sch]
2014-12-21 Changes for v1.1
    [controller.kicad_pcb, controller.sch, led_panels-veroboard.kicad_pcb]
2014-12-22 Fixes based on first real build.
    [controller.kicad_pcb, controller.sch]
2014-12-23 Tweaking the layout for home etching.
    [controller.kicad_pcb]
2014-12-23 Version 1.1.
    [controller.kicad_pcb]
2014-12-27 Updated parts list.
    [parts.xlsx]
